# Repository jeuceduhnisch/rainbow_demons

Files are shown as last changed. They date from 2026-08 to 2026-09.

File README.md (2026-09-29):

# Rainbow Demons

Rainbow Demons is an independently designed Daisy Patch SM Eurorack
buffer-manipulation instrument.

## Releases

- The repository root preserves the original tested working build from
  2026-08-11, including its firmware, documentation and fabrication files.
- `Rainbow_Demons_v2/` contains the corrected 18HP hardware revision.
- `Rainbow_Demons_v2/release/` contains firmware and documentation v2.0.1.
- `Rainbow_Demons_v2/Rainbow_Demons_v2.0.1.zip` is the current complete release.
- `Rainbow_Demons_v2/Rainbow_Demons_v2.0.0.zip` remains the immutable rollback
  package.

## Version 2.0.1

Version 2 adds:

- Clock-toggle recording in Slice and Scatter: start, stop/play, start fresh.
- A Mode 2 Feedback density control that creates increasingly frequent and
  shorter randomized recording windows clockwise.
- Physical Record and REC CV priority over Mode 2 automation.
- Automatic four-second Slice and eight-second Scatter capture limits.
- A hardware-tested audio block-size correction that moves the callback cadence
  from an audible 3 kHz to 24 kHz and removes the high-pitched harmonic comb.

The v2.0.1 firmware was built, flashed, and tested on the target module on
2026-09-29. Tape, Slice, Scatter, recording, playback, three-head operation,
controls and mode switching passed without reported crackling or dropouts.

## Independent-design disclaimer

Rainbow Demons is inspired by broad buffer-manipulation ideas associated with
MTL ASM's Count to 5. It is not a clone, reproduction, port, or claim of exact
pedal behavior. No original source code, firmware, schematics, PCB files, or
proprietary design material were used. This project is not affiliated with or
endorsed by MTL ASM.

## License

This project is released under the Unlicense. See [LICENSE](LICENSE).

## Acknowledgments

Documentation, cleanup, and release organization were assisted by OpenAI Codex.

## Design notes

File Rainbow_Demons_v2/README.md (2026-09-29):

# Rainbow Demons v2

## Tape Delay 18HP All-In-One PCB and Faceplate

This revision corrects the Alpha RD901F potentiometer and QingPu WQP-PJ398SM / Thonkiconn footprints, fixes the rear-mounted Daisy Patch SM pin mirroring, and removes the carrier PCB material behind the top and bottom Eurorack rails. The separate faceplate remains the full 128.5 mm Eurorack height.

Electrical notes:

- 10-pin Eurorack power is routed as pins 1-2 `-12V`, pins 3-8 `GND`, pins 9-10 `+12V`.
- The Patch SM `3V3` output on A10 feeds the five potentiometer high-side pins.
- The Patch SM `5V` output is not used by this tape-delay control board.
- Potentiometers are wired as `GND / wiper signal / 3V3`.
- Pot electrical pads are on 2.50 mm centers and mounting tabs are 9.60 mm apart, matching KiCad's official Alpha RD901F-40-00D footprint.
- RV2 is rotated 180 degrees behind the panel so its real Alpha-style pin row clears the Daisy Patch SM A5/A6 area.
- FREEZE and REVERSE are momentary switches to ground using the Wurth `430476085716` 12 x 12 mm THT footprint.
- Each LED has two LED holes plus two inline series-resistor holes; install a resistor between `R_SIG` and `R_LED_A`.
- The square/rectangular LED hole is cathode/ground.
- The square/rectangular jack hole is sleeve/ground.
- Jack pad centers are sleeve `-6.48 mm`, switch normal `-3.38 mm`, and tip `+4.92 mm` relative to the panel jack center.
- Each jack includes the manufacturer-recommended 3.0 mm NPTH beneath the barrel center.
- The populated carrier outline is 91.44 x 111.50 mm, spanning panel coordinates y=8.50 through y=120.00; there is no carrier material in either rail zone.
- The rear-mounted Patch SM footprint is mirrored before rotation so carrier A1 lands on module A1, A5 on A5, and all other named pins remain one-to-one.
- IN R is normalled from IN L through the jack switch contact.
- IN R is normalled from IN L. The OUT L and OUT R switch contacts are intentionally unconnected.

Fabrication status:

- The main PCB and faceplate were generated as KiCad 10 PCB files.
- KiCad CLI DRC on 2026-07-21 reported 0 violations and 0 unconnected items for both generated boards.
- Run KiCad DRC again before ordering after any manual edits.
- This layout uses generic 9 mm vertical pot, QingPu/Thonkiconn PJ398SM-style 3-pin jack, and 5 mm LED footprints. Verify against the exact parts you will buy before a full production order.

Files:

- `tape_delay_all_in_one_18hp_v2.kicad_pcb`: routed main PCB with corrected footprints, power mapping, and rail clearance.
- `tape_delay_faceplate_18hp_v2.kicad_pcb`: matching full-height FR4 faceplate.
- `faceplate_editable.svg`: editable faceplate art/text template.
- `tape_delay_all_in_one_wiring_map.csv`: Patch SM pin assignments.
- `main_gerbers.zip`: main PCB fabrication package, after export.
- `faceplate_gerbers.zip`: faceplate fabrication package, after export.

## Firmware and build release 2.0.1

The complete clock-toggle and random-density firmware release is in
`release/`. It includes source, flashable binary, BOM, build guide, PCB
modifications, quick start and the six-page combined manual.

The packaged current release is `Rainbow_Demons_v2.0.1.zip`; the unchanged
`Rainbow_Demons_v2.0.0.zip` is retained for rollback. Version 2 adds clock-edge
start/stop recording in Slice and Scatter plus randomized Mode 2 recording
density on the Feedback control. Version 2.0.1 changes only the audio block
size from 16 to 2, moving the callback cadence from 3 kHz to 24 kHz. The new
firmware built, flashed and passed the complete hands-on mode test on
2026-09-29 without reported crackling or dropouts.

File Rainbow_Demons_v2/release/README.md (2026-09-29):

# Rainbow Demons v2.0.1

Version: 2.0.1
Release date: 2026-09-29

This package preserves the tested DIY Eurorack instrument, its established
recording behavior, the 2026-09-29 callback-noise correction and the tape-delay
PCB fabrication files actually used for the build.

## Independent-design disclaimer

Rainbow Demons is an independently designed instrument inspired by broad
buffer-manipulation ideas associated with MTL ASM's Count to 5. It is not a
clone, reproduction, port, or claim of exact pedal behavior. No original source
code, firmware, schematics, PCB files, or proprietary design material were
used. This project is not affiliated with or endorsed by MTL ASM.

## Start here

1. Read `PCB_MODIFICATIONS.md` before powering the tape-delay PCB.
2. Build from `BUILD_GUIDE.md` and `BOM.md`.
3. Flash `firmware/build/RainbowDemons.bin` or rebuild from source.
4. Use `QUICK_START.md` for the final control map.

The same material is combined into `Rainbow_Demons_Build_Documentation.pdf`.

## Package layout

- Top level - concise build guide, PCB changes, BOM, quick start and PDF.
- `firmware/` - final source, Makefile, startup file and verified binary.
- `pcb/` - tape-delay main PCB/faceplate Gerbers, source and base wiring map.

## Release firmware

- Binary size and SHA-256: see `firmware/BUILD_MANIFEST.txt` for the verified
  v2.0.1 build identity.
- Audio block size: 2 samples at 48 kHz; callback cadence 24 kHz
- Noise correction: removes the audible 3 kHz callback-rate harmonic comb
- Mode 3 head range: 1/8x to 8x, or -3 to +3 octaves
- Mix: counter-clockwise dry, clockwise wet, with hard digital endpoints
- REC CV alternates capture on successive clock edges: start / stop / start new
- Slice Feedback controls random-record density; clockwise produces more
  frequent, shorter windows; manual Record or the first
  REC CV edge takes priority until Reset or a mode change
- Changing Mode clears captured audio and invalidates the previous phrase

Hardware acceptance on 2026-09-29 passed Tape, Slice and Scatter, including
recording/playback, three heads, controls and mode switching, with no reported
crackling or dropouts.

## Gerber note

The included Gerbers are the tape-delay PCB files used for this build. They do
not contain the documented 100k pulldown, Reset-trigger bodge or new toggle
wiring as copper changes; apply those modifications manually.

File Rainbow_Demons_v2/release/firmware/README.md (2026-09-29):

# Final firmware

This source/binary pair is v2.0.1, the 2026-09-29 hardware-tested release. It
preserves the v2.0.0 behavior and changes the audio block size from 16 to 2 to
move the callback cadence from an audible 3 kHz to 24 kHz.

This is independent clean-room firmware for Rainbow Demons. See the top-level
README for the independent-design disclaimer.

## Flash the supplied binary

Enter DFU mode by holding BOOT, tapping RESET and releasing BOOT, then run from
Git Bash:

```sh
make program-dfu
```

## Rebuild and flash

```sh
make clean && make && make program-dfu
```

The Makefile falls back to the known-good SDK at
`C:/Users/Jeuce/Documents/Codex/2026-07-07/i-h/work`. On another system,
override `LIBDAISY_DIR` and `DAISYSP_DIR` on the command line.

See `BUILD_MANIFEST.txt` for the accepted binary hash and behavior summary.

## Callback-noise correction

The v2.0.0 build used a 16-sample block at 48 kHz. A phone recording showed a
stable comb at approximately 3, 6, 9 and 12 kHz, matching the 3 kHz callback
rate and its harmonics. The 2-sample diagnostic removed the audible squeal and
passed Tape, Slice and Scatter stress testing on the built module. No DSP,
control-map or hardware-pin behavior changed in v2.0.1.

## REC trigger behavior

In Slice and Scatter, successive rising edges on `GATE_IN_1/B10` alternate:

1. Start a fresh capture.
2. Stop capture and begin playback.
3. Start another fresh capture.

Slice still stops automatically at four seconds and Scatter at eight seconds.
The physical Record button retains hold-to-record behavior.

## Slice automatic recording

In Slice, Feedback is an internal random-record density control. Full
counter-clockwise disables it. Turning clockwise makes capture events more
frequent and their windows shorter: roughly 1.25-3.75 seconds near the sparse
end, 0.3-0.9 seconds near noon and 0.06-0.2 seconds fully clockwise.

A physical Record press or the first REC trigger edge latches manual/external
priority and disables the generator until Reset is pressed or the mode is
changed. The gate input cannot detect a cable held at 0 V, so external priority
begins on the first received rising edge, not at physical cable insertion.

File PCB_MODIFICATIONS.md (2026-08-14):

# Required modifications to the reused tape-delay PCB

These modifications convert the included tape-delay PCB wiring for Rainbow
Demons. See the top-level README for the independent-design disclaimer.

These changes match the final working firmware. Perform continuity checks with
the module unpowered.

## Required

1. **Audio-input pulldown:** add a 100k resistor from the audio input jack's
   switched/normal contact to GND. This prevents an open input from floating.
2. **Reset trigger:** the original CLOCK OUT tip runs to `B6/GATE_OUT_2`, which
   is an output. Isolate or ignore that trace and wire the jack tip to
   `B9/GATE_IN_2`. Keep the sleeve at GND.
3. **Record trigger:** retain the CLOCK IN connection to `B10/GATE_IN_1`.
4. **Buttons:** Record goes to `D1`; Reset goes to `D2`. Each button shorts its
   pin to GND when pressed.
5. **Mode toggle:** SPDT ON-OFF-ON, common to GND, outer lugs to `D7` and `D10`.
6. **Direction toggle:** common to GND, outer lugs to `D3` and `D4`.
7. **Quantize toggle:** common to GND, outer lugs to `D5` and `D6`.
8. **LEDs:** Record LED is driven from `B8`; Status LED from `B7`. Each LED
   requires a series resistor. The existing TEMPO/B8 position normally already
   has one; add 1k at B7 if the reused footprint has none.

## Final analog connections

| Panel control | Patch SM pin |
|---|---|
| Time pot | `A2 / ADC_9` |
| Feedback pot | `C8 / CV_7` |
| Mix pot | `C9 / CV_8` |
| Filter pot | `A3 / ADC_10` |
| Flutter pot | `D9 / ADC_11` |
| CV1 Time | `C5 / CV_1` |
| CV2 Filter | `C4 / CV_2` |
| CV3 Flutter | `C3 / CV_3` |
| CV4 Feedback | `C2 / CV_4` |
| CV5 | `C6 / CV_5`; unused by final firmware |
| Mono input | `B4 / AUDIO_IN_LEFT` |
| Main output | `B2 / AUDIO_OUT_LEFT` |
| Optional second output | `B1 / AUDIO_OUT_RIGHT` |

The final firmware reduced the recording-path overload that caused the
high-frequency tone. No additional input attenuator is required on the tested
module. Keep the 100k switched-contact pulldown.

## Leave disconnected

- Original `B6/GATE_OUT_2` connection to the repurposed Reset trigger jack.
- `B5/FREEZE LED`, unless deliberately repurposed in a future firmware build.
- Audio-input-right if building the tested mono version.
- CV5-to-Mix modulation; it is disabled so Mix can reach exact dry/wet endpoints.

## Unpowered checks

- No short between +12V, -12V, 5V, 3V3 and GND.
- Audio input normal contact measures about 100k to GND with no cable inserted.
- Trigger sleeves and toggle commons have continuity to GND.
- Reset trigger tip reaches B9 and does not reach B6.
- Eurorack red stripe reaches the PCB's marked -12V end.

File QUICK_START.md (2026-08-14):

# Quick start

These controls describe Rainbow Demons. See the top-level README for the
independent-design disclaimer.

## Global controls

| Control | Function |
|---|---|
| Mode toggle | Up Tape / center Slice / down Scatter |
| Direction toggle | Outer positions force forward or reverse; center is knob-controlled |
| Quantize toggle | Outer positions select semitone or octave; center is free |
| Mix | Counter-clockwise dry / clockwise wet |
| Record | Hold to capture in Slice or Scatter; release to play |
| Reset | Tap to restart heads; hold 1.2 seconds to erase |

Changing Mode clears all captured audio.

The final firmware reads the two outside toggle contacts directly. If an outer
position does not match the engraved panel word, exchange that toggle's two
outside wires; its center behavior does not change.

## Tape - pitch-shifted/reverse delay

| Knob | Function |
|---|---|
| Time | Read-head direction, speed and pitch |
| Feedback | Processed signal returned to the buffer |
| Mix | Dry/delay balance |
| Filter | Lo-fi bandwidth and brightness |
| Flutter | Stepped buffer length, about 31 ms to 8 s |

For unstable harmonized pitch spirals, raise Feedback and move Time away from unity.

## Slice - asynchronous random sampler

Hold Record for a phrase up to four seconds, then release.

| Knob | Function |
|---|---|
| Time | Slice direction, speed and pitch |
| Feedback | Reserved |
| Mix | Dry/sliced-sample balance |
| Filter | Random start probability/range |
| Flutter | Slice length, grains to full phrase |

## Scatter - one to three tape heads

Hold Record for a phrase up to eight seconds, then release.

| Knob | Function |
|---|---|
| Time | Head 1 direction/speed |
| Feedback | Head 2 direction/speed |
| Filter | Head 3 direction/speed |
| Flutter | One, two or three active heads |
| Mix | Dry/multi-head loop balance |

With Direction centered, each head runs reverse left of noon, stops near noon
and runs forward right of noon. Each spans 1/8x to 8x (-3 to +3 octaves), with
approximately 1x near 1:30.

## Reliable initial test settings

- Direction and Quantize centered.
- Time, Feedback and Filter at noon.
- Flutter at 2 o'clock.
- Leave CV inputs unpatched.
- Change only Mix while checking dry/wet behavior.

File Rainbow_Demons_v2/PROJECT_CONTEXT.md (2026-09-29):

# Rainbow Demons project context

Current release: v2.0.1, 2026-09-29.

The module is built from the Tape Delay V2 carrier PCB with the documented
100k input pulldown, B9 Reset-trigger bodge and Rainbow Demons control wiring.
The current firmware uses a 2-sample audio block at 48 kHz. This replaces the
v2.0.0 16-sample setting whose 3 kHz callback cadence produced an audible
harmonic comb on the built module.

The v2.0.1 binary was compiled, flashed and hardware-tested. Tape, Slice,
Scatter, recording/playback, all three Scatter heads, controls and mode
switching passed without reported crackling or dropouts.

Do not overwrite `Rainbow_Demons_v2.0.0.zip`; it is the rollback package.
Future experiments belong in new versioned folders or branches.

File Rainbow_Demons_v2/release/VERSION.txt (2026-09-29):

Module: Rainbow Demons
Release: v2.0.1
Date: 2026-09-29
Status: RELEASED - firmware built, flashed and hardware-tested
Source task: 019f78d2-ce77-7970-9f07-954e1e9a1d2a

Change summary:
- Audio block size changed from 16 to 2 samples at 48 kHz.
- Callback cadence moved from 3 kHz to 24 kHz.
- Audible callback-rate harmonic comb was no longer present in the hardware test.
- No DSP, control-map, pinout, PCB or panel change.

Verification:
- Clean firmware build passed.
- Binary size: 88252 bytes.
- SHA-256: C02E43BDFAF3293CE66D482667BFC05E70C1547ACF37449F2CC3C53EE25D94E8
- DFU flash passed.
- Tape, Slice, Scatter, recording/playback, three heads, controls and mode
  switching passed without reported crackling or dropouts.

Artifact status:
- Schematic/circuit explanation: Included in build documentation.
- BOM: Included.
- Physical PCB/layout files: Included as KiCad source and Gerbers.
- External wiring and PCB modifications: Included.
- Power and connector information: Included.
- Firmware source/build/upload instructions: Included.
- Bring-up and acceptance testing: Included.
- Editable sources and PDF: Included.

Rollback:
- Rainbow_Demons_v2.0.0.zip remains unchanged.

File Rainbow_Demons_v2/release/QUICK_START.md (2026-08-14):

# Quick start

These controls describe Rainbow Demons. See the top-level README for the
independent-design disclaimer.

## Global controls

| Control | Function |
|---|---|
| Mode toggle | Up Tape / center Slice / down Scatter |
| Direction toggle | Outer positions force forward or reverse; center is knob-controlled |
| Quantize toggle | Outer positions select semitone or octave; center is free |
| Mix | Counter-clockwise dry / clockwise wet |
| Record | Hold to capture in Slice or Scatter; release to play |
| REC CV | Rising pulses alternate: start / stop-and-play / start fresh |
| Reset | Tap to restart heads; hold 1.2 seconds to erase |

Changing Mode clears all captured audio.

For clocked recording, patch a standard positive Eurorack clock to REC CV
(0V low, +5V high recommended). Pulse width is not used; each rising edge
changes the capture state. If capture reaches four seconds in Slice or eight
seconds in Scatter, it stops automatically and the next pulse starts fresh.
RESET CV only restarts the playback heads; it does not begin a recording.

The final firmware reads the two outside toggle contacts directly. If an outer
position does not match the engraved panel word, exchange that toggle's two
outside wires; its center behavior does not change.

## Tape - pitch-shifted/reverse delay

| Knob | Function |
|---|---|
| Time | Read-head direction, speed and pitch |
| Feedback | Processed signal returned to the buffer |
| Mix | Dry/delay balance |
| Filter | Lo-fi bandwidth and brightness |
| Flutter | Stepped buffer length, about 31 ms to 8 s |

For unstable harmonized pitch spirals, raise Feedback and move Time away from unity.

## Slice - asynchronous random sampler

Hold Record for a phrase up to four seconds, then release.

| Knob | Function |
|---|---|
| Time | Slice direction, speed and pitch |
| Feedback | Auto-record density: clockwise makes captures more frequent and shorter |
| Mix | Dry/sliced-sample balance |
| Filter | Random start probability/range |
| Flutter | Slice length, grains to full phrase |

With Feedback above its CCW off zone, Slice automatically records random
windows. Sparse settings produce roughly 1.25-3.75-second captures; noon gives
about 0.3-0.9 seconds; fully clockwise gives about 0.06-0.2 seconds. Clockwise
also shortens the random wait between windows. Pressing Record or sending the
first REC CV pulse takes manual/external priority; automatic recording remains
disabled until Reset is pressed or you leave and return to Slice. Because the
digital input senses voltage rather than cable insertion, an inserted cable at
0 V is recognized only when its first rising edge arrives.

## Scatter - one to three tape heads

Hold Record for a phrase up to eight seconds, then release.

| Knob | Function |
|---|---|
| Time | Head 1 direction/speed |
| Feedback | Head 2 direction/speed |
| Filter | Head 3 direction/speed |
| Flutter | One, two or three active heads |
| Mix | Dry/multi-head loop balance |

With Direction centered, each head runs reverse left of noon, stops near noon
and runs forward right of noon. Each spans 1/8x to 8x (-3 to +3 octaves), with
approximately 1x near 1:30.

## Reliable initial test settings

- Direction and Quantize centered.
- Time and Filter at noon.
- Feedback at noon for Tape/Scatter; fully CCW for predictable manual Slice
  testing. Mode 2 no longer has a neutral noon Feedback setting.
- Flutter at 2 o'clock.
- Leave CV inputs unpatched.
- Change only Mix while checking dry/wet behavior.

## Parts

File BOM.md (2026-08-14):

# Final BOM

Quantities describe the tested mono Rainbow Demons build. The optional second output may
be added if the panel has room.

| Category | Qty | Part / value | Notes |
|---|---:|---|---|
| DSP | 1 | Electrosmith Daisy Patch SM | Main processor and Eurorack I/O conditioning |
| Main PCB | 1 | Tape-delay all-in-one Patch SM PCB | Main Gerbers included |
| Patch SM sockets | 4 | 1x10, 2.54 mm female headers | Keep the Patch SM removable |
| Power header | 1 | 2x5 keyed Eurorack header | Red stripe = -12V |
| Power cable | 1 | 10-to-16-pin Eurorack ribbon | Verify orientation at both ends |
| Pots | 5 | B10K linear | Time, Feedback, Mix, Filter, Flutter |
| Knobs | 5 | To fit pot shafts | About 10-12 mm diameter |
| Toggles | 3 | SPDT ON-OFF-ON | Mode, Direction, Quantize; common to GND |
| Buttons | 2 | SPST-NO momentary | Record and Reset |
| LEDs | 2 | 3 mm or 5 mm diffused | Record and Status |
| LED resistors | 2 | 1k, 0.25 W | One may already exist at TEMPO/B8 |
| Input pulldown | 1 | 100k, 0.25 W | Input switched contact to GND |
| Jacks | 9 | PJ398SM/PJ301M-12-style switched 3.5 mm | 5 CV, 2 trigger, mono in, mono out |
| Optional output jack | 1 | Same as above | Connect to B1 for mirrored output |
| Perfboard | 1 | 2.54 mm isolated pad-per-hole | Only if controls are not PCB-mounted |
| Hookup wire | 1 lot | 26-28 AWG stranded | Color-code power, ground, analog and digital |
| Bus wire | 1 lot | 22-24 AWG tinned solid | Ground/power buses if using perfboard |
| Heat-shrink | 1 kit | 1.5-4 mm | Insulate panel terminals and bodges |
| Standoffs/hardware | 1 set | M2.5/M3 nylon or insulated | Support carrier and perfboard independently |
| Front panel | 1 | Matching tape-delay PCB panel | Faceplate Gerbers included |

## Optional noise filtering

For long hand-wired pot leads, add one 1k resistor in series with each of the
five pot wipers and optionally 10 nF from the Patch SM side of each resistor to
GND. These are noise-control parts, not required for basic operation.

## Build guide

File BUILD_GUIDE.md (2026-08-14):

# Concise build guide

This guide builds Rainbow Demons using the tape-delay PCB and final firmware in
this package. See the top-level README for the independent-design disclaimer.

## 1. Mechanical dry fit

Dry-fit the panel, pots, toggles, buttons, LEDs, jacks, Patch SM carrier and any
perfboard before soldering. Confirm rail clearance, USB/BOOT access and that no
metal hardware can contact perfboard copper.

## 2. Power and carrier

Install the keyed 10-pin Eurorack header with the marked -12V edge at the red
stripe. Socket the Patch SM if possible. Do not feed external 5V or 3V3 into the
Patch SM output rails.

## 3. Pots and CV

Wire the five pots and CV jacks exactly as listed in `PCB_MODIFICATIONS.md`.
Pot end terminals go to the appropriate supply and GND; the wiper goes to the
listed ADC/CV pin. Ground every jack sleeve. CV inputs are already conditioned
by the Patch SM, so external attenuators are optional.

## 4. Audio and triggers

- Mono input tip -> B4; sleeve -> GND.
- Add 100k from the input jack switched/normal contact to GND.
- Main output tip -> B2; optional mirrored output -> B1.
- Record trigger tip -> B10.
- Isolate the reused Reset jack from B6 and wire its tip -> B9.

## 5. Digital controls

- Record button -> D1 to GND.
- Reset button -> D2 to GND.
- Mode toggle outer lugs -> D7/D10; common -> GND.
- Direction toggle outer lugs -> D3/D4; common -> GND.
- Quantize toggle outer lugs -> D5/D6; common -> GND.
- Record LED -> B8 through 1k; Status LED -> B7 through 1k; cathodes -> GND.

If a toggle reads upside-down, exchange only its two outside wires.

## 6. Unpowered inspection

Check the rail isolation, red-stripe orientation, B9 Reset bodge, 100k input
pulldown, LED polarity/resistors, jack grounds and adjacent-header shorts.

## 7. Flash firmware

Put the Patch SM in DFU mode: hold BOOT, tap RESET, then release BOOT. From Git
Bash in the included `firmware` directory run:

```sh
make program-dfu
```

To rebuild first:

```sh
make clean && make && make program-dfu
```

The supplied Makefile uses the complete SDK at
`C:/Users/Jeuce/Documents/Codex/2026-07-07/i-h/work` when the nearby
DaisyExamples SDK is incomplete. Override `LIBDAISY_DIR` and `DAISYSP_DIR` on
the make command line on another computer.

## 8. First power and acceptance test

1. Power from a current-limited/test Eurorack supply if available.
2. Confirm no component heats and the Patch SM starts normally.
3. With Mix fully counter-clockwise, confirm clean dry audio.
4. With Mix fully clockwise, confirm no direct-signal leakage.
5. Record and play a phrase in Slice.
6. Record in Scatter; verify three heads with Flutter high.
7. In Scatter, verify Time, Feedback and Filter run reverse-left, stop near
   noon and run forward-right with Direction centered.
8. Change modes and return; the old capture must not resume.

Do not install the module in the main case until these checks pass.

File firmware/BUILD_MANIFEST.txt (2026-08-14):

Rainbow Demons - final working firmware
Release: 2026-08-11
Target: Daisy Patch SM / STM32H750
Source: RainbowDemons.cpp
Binary: build/RainbowDemons.bin
Binary size: 87208 bytes
SHA-256: 661A7DB0510F7DD0625B3B4981CDC01A40592A78591653F14ADCE66548FBF970
Build command: make clean && make
Flash command: make program-dfu

Independent-design notice: see the top-level README.

Acceptance status reported by builder:
- Mix reaches true dry; working wet endpoint confirmed.
- 100k input pulldown fixed open-input behavior.
- Mode 3 head 2 direction and center calibrated.
- Mode 3 range set to -3 through +3 octaves.
- Mode changes invalidate and clear the previous capture.

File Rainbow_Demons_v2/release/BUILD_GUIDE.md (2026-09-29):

# Concise build guide

This guide builds Rainbow Demons using the tape-delay PCB and final firmware in
this package. See the top-level README for the independent-design disclaimer.

## 1. Mechanical dry fit

Dry-fit the panel, pots, toggles, buttons, LEDs, jacks, Patch SM carrier and any
perfboard before soldering. Confirm rail clearance, USB/BOOT access and that no
metal hardware can contact perfboard copper.

## 2. Power and carrier

Install the keyed 10-pin Eurorack header with the marked -12V edge at the red
stripe. Socket the Patch SM if possible. Do not feed external 5V or 3V3 into the
Patch SM output rails.

## 3. Pots and CV

Wire the five pots and CV jacks exactly as listed in `PCB_MODIFICATIONS.md`.
Pot end terminals go to the appropriate supply and GND; the wiper goes to the
listed ADC/CV pin. Ground every jack sleeve. CV inputs are already conditioned
by the Patch SM, so external attenuators are optional.

## 4. Audio and triggers

- Mono input tip -> B4; sleeve -> GND.
- Add 100k from the input jack switched/normal contact to GND.
- Main output tip -> B2; optional mirrored output -> B1.
- Record trigger tip -> B10. Successive rising clock edges perform
  start-recording / stop-and-play / start-new-recording.
- Isolate the reused Reset jack from B6 and wire its tip -> B9.

## 5. Digital controls

- Record button -> D1 to GND.
- Reset button -> D2 to GND.
- Mode toggle outer lugs -> D7/D10; common -> GND.
- Direction toggle outer lugs -> D3/D4; common -> GND.
- Quantize toggle outer lugs -> D5/D6; common -> GND.
- Record LED -> B8 through 1k; Status LED -> B7 through 1k; cathodes -> GND.

If a toggle reads upside-down, exchange only its two outside wires.

## 6. Unpowered inspection

Check the rail isolation, red-stripe orientation, B9 Reset bodge, 100k input
pulldown, LED polarity/resistors, jack grounds and adjacent-header shorts.

## 7. Flash firmware

Put the Patch SM in DFU mode: hold BOOT, tap RESET, then release BOOT. From Git
Bash in the included `firmware` directory run:

```sh
make program-dfu
```

To rebuild first:

```sh
make clean && make && make program-dfu
```

The supplied Makefile uses the complete SDK at
`C:/Users/Jeuce/Documents/Codex/2026-07-07/i-h/work` when the nearby
DaisyExamples SDK is incomplete. Override `LIBDAISY_DIR` and `DAISYSP_DIR` on
the make command line on another computer.

## 8. First power and acceptance test

1. Power from a current-limited/test Eurorack supply if available.
2. Confirm no component heats and the Patch SM starts normally.
3. With Mix fully counter-clockwise, confirm clean dry audio.
4. With Mix fully clockwise, confirm no direct-signal leakage.
5. Record and play a phrase in Slice.
6. Record in Scatter; verify three heads with Flutter high.
7. In Slice or Scatter, send three REC trigger pulses: pulse 1 starts capture,
   pulse 2 stops for playback, and pulse 3 starts a fresh capture.
8. In Scatter, verify Time, Feedback and Filter run reverse-left, stop near
   noon and run forward-right with Direction centered.
9. Change modes and return; the old capture must not resume.
10. In Slice, turn Feedback fully CCW and confirm automatic recording is off.
    Turn it clockwise and confirm randomized capture windows become more
    frequent and shorter. Press Record or send a REC pulse and confirm
    automation yields until Reset or a mode change.
11. With the input grounded and USB disconnected, listen at dry, noon and wet
    Mix positions. The previous 3 kHz callback squeal should not be audible.
12. Stress Tape at high feedback, Slice at maximum density, and Scatter with
    all three heads. Stop if crackling or audio dropouts occur.

Do not install the module in the main case until these checks pass.

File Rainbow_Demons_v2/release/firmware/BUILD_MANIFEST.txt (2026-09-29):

Rainbow Demons - final working firmware
Version: 2.0.1
Release: 2026-09-29
Target: Daisy Patch SM / STM32H750
Source: RainbowDemons.cpp
Binary: build/RainbowDemons.bin
Binary size: 88252 bytes
SHA-256: C02E43BDFAF3293CE66D482667BFC05E70C1547ACF37449F2CC3C53EE25D94E8
Build command: make clean && make
Flash command: make program-dfu

Independent-design notice: see the top-level README.

Working-baseline acceptance status reported by builder:
- Mix reaches true dry; working wet endpoint confirmed.
- 100k input pulldown fixed open-input behavior.
- Mode 3 head 2 direction and center calibrated.
- Mode 3 range set to -3 through +3 octaves.

2026-08-13 additions (build verified; hardware test pending):
- REC trigger pulses alternate start / stop / start-new capture.
- Slice Feedback controls automatic-record density (more frequent and shorter
  clockwise); Record or the
  first REC pulse latches manual/external priority until Reset or mode change.
- Mode changes invalidate and clear the previous capture.

2026-09-29 callback-noise correction (build, flash and hardware test passed):
- Audio block size changed from 16 to 2 samples at 48 kHz.
- Callback cadence moved from 3 kHz to 24 kHz.
- The audible 3/6/9/12 kHz harmonic comb was no longer present in the hardware test.
- Tape, Slice, Scatter, recording/playback, three heads, controls and mode
  switching passed without reported crackling or dropouts.

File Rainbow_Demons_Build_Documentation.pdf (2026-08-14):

Rainbow Demons - independent Patch SM instrument - 2026-08-11 | Page 1

# Rainbow Demons

## An original, independently designed Eurorack instrument

Release | Platform | Format | Firmware status
2026-08-11 | Daisy Patch SM | Tape-delay PCB / mono | Built and user-verified

# What this package contains

- Final source, Makefile, startup file and verified flashable binary.
- Tape-delay main PCB and faceplate Gerbers plus editable PCB source.
- Required PCB modifications, BOM, build sequence, acceptance test and quick-start control map.

# Critical proven modifications

Add 100k from the audio-input switched contact to GND. Move the repurposed Reset-trigger tip from B6 to B9/GATE_IN_2. Record is D1, Reset is D2, Record LED is B8 and Status LED is B7. Feedback uses CV_7/C8. Do not restore obsolete ADC_12, D7/D10-button or B5/B6-LED assignments.

## Verified behavior

- Mix is counter-clockwise dry and clockwise wet with exact digital endpoints.
- Tape provides lo-fi pitch/reverse delay and high-feedback pitch spirals.
- Slice captures up to 4 seconds; Scatter captures up to 8 seconds.
- Scatter heads span 1/8x to 8x (-3 to +3 octaves) and stop near noon.
- Changing Mode clears and invalidates the previous capture.

## Independent-design disclaimer

Rainbow Demons is inspired by broad buffer-manipulation ideas associated with MTL ASM's Count to 5. It is not a clone, reproduction, port, or claim of exact pedal behavior. No original source code, firmware, schematics, PCB files, or proprietary design material were used. This project is not affiliated with or endorsed by MTL ASM.

Rainbow Demons - independent Patch SM instrument - 2026-08-11 | Page 2

# 1. Required tape-delay PCB changes

Change | Final connection | Reason
Input pulldown | 100k: input switched/normal contact to GND | Stops floating open input
Reset trigger | Isolate original B6 trace; jack tip to B9 | B6 is an output; B9 is GATE_IN_2
Record trigger | Jack tip to B10 | GATE_IN_1
Buttons | Record D1; Reset D2; other side GND | Matches final panel/firmware
Mode toggle | Outer lugs D7/D10; common GND | Tape / Slice / Scatter
Direction | Outer lugs D3/D4; common GND | Reverse / variable / forward
Quantize | Outer lugs D5/D6; common GND | Semitone / free / octave
LEDs | B8 Record; B7 Status; each through 1k | Plain GPIO indicators

## Final signal map

Function | Pin | Function | Pin
Time pot | A2 / ADC_9 | CV1 Time | C5 / CV_1
Feedback pot | C8 / CV_7 | CV2 Filter | C4 / CV_2
Mix pot | C9 / CV_8 | CV3 Flutter | C3 / CV_3
Filter pot | A3 / ADC_10 | CV4 Feedback | C2 / CV_4
Flutter pot | D9 / ADC_11 | CV5 | C6 / disabled
Mono input | B4 | Main output | B2
Optional output | B1 | Ground | Jack sleeves / commons

## Leave disconnected

- B6 from the repurposed Reset trigger jack; B5 FREEZE LED; audio-input-right in the mono build.
- CV5-to-Mix modulation. The final firmware disables it to preserve exact Mix endpoints.

## Unpowered checks

- No shorts among +12V, -12V, 5V, 3V3 and GND; red stripe reaches marked -12V.
- Input normal contact measures about 100k to GND; Reset tip reaches B9 and not B6.
- Toggle commons and jack sleeves reach GND; LEDs have correct polarity and series resistors.

Rainbow Demons - independent Patch SM instrument - 2026-08-11 | Page 3

# 2. Bill of materials

Qty | Part | Specification / note
1 | Daisy Patch SM | DSP and conditioned Eurorack I/O
1 | Tape-delay main PCB | Main Gerbers included
4 | Patch SM sockets | 1x10, 2.54 mm female headers
1 | Power header + cable | 2x5 keyed; 10-to-16-pin ribbon; red stripe -12V
5 | Potentiometers + knobs | B10K linear; Time, Feedback, Mix, Filter, Flutter
3 | Toggles | SPDT ON-OFF-ON, panel mount
2 | Buttons | SPST-NO momentary, Record and Reset
2 | LEDs + 1k resistors | Diffused 3 or 5 mm; Record and Status
1 | 100k resistor | 0.25 W input switched-contact pulldown
9 | Switched 3.5 mm jacks | 5 CV, 2 trigger, mono input, mono output
1 opt. | Second output jack | Tip to B1 for mirrored output
1 | Perfboard | 2.54 mm isolated pad-per-hole if controls are hand-wired
1 lot | Wire / heat-shrink | 26-28 AWG stranded; 22-24 AWG tinned bus wire
1 set | Insulated hardware | M2.5/M3 standoffs, washers, rack screws
1 | Front panel | Matching faceplate Gerbers included

## Optional hand-wiring filter

For long pot leads, add 1k in series with each of five wipers and optionally 10 nF from the Patch SM side of each resistor to GND. These parts reduce pickup; they are not required for basic operation.

## Mechanical rules

- Dry-fit every control, carrier and perfboard before soldering; preserve rail and USB/BOOT clearance.
- Support carrier and perfboard with insulated hardware. Never let perfboard copper rest on the carrier.
- Verify exact pot shaft/bushing, toggle action and jack footprint against purchased parts.

Rainbow Demons - independent Patch SM instrument - 2026-08-11 | Page 4

# 3. Assembly, flashing and checkout

Step | Task | Action
1 | Mechanical dry fit | Fit panel controls, carrier and brackets. Confirm rail and USB/BOOT access.
2 | Power | Install keyed header with red stripe at -12V. Do not feed external 5V/3V3 into Patch SM outputs.
3 | Analog wiring | Wire pots/CVs per page 2. Ground sleeves. Add the 100k input pulldown.
4 | Audio/triggers | Input B4; output B2; Record trigger B10; isolate B6 and bodge Reset trigger to B9.
5 | Digital wiring | Record D1, Reset D2, toggles D3/D4/D5/D6/D7/D10, LEDs B8/B7.
6 | Inspect | Meter rails, grounds, pulldown, B9 bodge, LED polarity and adjacent-header shorts.

## Flash

Enter DFU: hold BOOT, tap RESET, release BOOT. In Git Bash inside the firmware folder:

Use | Command
Flash supplied build | make program-dfu
Clean rebuild + flash | make clean && make && make program-dfu

## Acceptance test

- Power from a test/current-limited supply; stop if anything heats or current is abnormal.
- Mix fully counter-clockwise: clean dry audio. Fully clockwise: wet only, no direct leakage.
- Slice: hold Record, capture a phrase, release and hear playback.
- Scatter: capture, raise Flutter for three heads; Time/Feedback/Filter reverse left, stop near noon, forward right.
- Change Mode and return. The old phrase must not resume.

## Binary identity

RainbowDemons.bin - final binary identity is listed in BUILD_MANIFEST.txt.
661A7DB0510F7DD0625B3B4981CDC01A40592A78591653F14ADCE66548FBF970

Rainbow Demons - independent Patch SM instrument - 2026-08-11 | Page 5

# 4. Quick start

Global control | Action
Mode | Up Tape / center Slice / down Scatter
Direction | Outer positions force direction; center lets DIR knobs cross reverse-stop-forward
Quantize | Outer positions select semitone/octave; center is free
Mix | Counter-clockwise dry / clockwise wet
Record | Hold to capture in Slice/Scatter; release to play
Reset | Tap restarts heads; hold 1.2 seconds erases
If an outer toggle label is reversed, exchange only that toggle's two outside wires.

## Mode control map

Knob | Tape | Slice | Scatter
Time | Read-head speed/direction | Slice speed/direction | Head 1 speed/direction
Feedback | Feedback amount | Reserved | Head 2 speed/direction
Mix | Dry/delay | Dry/slices | Dry/multi-head loop
Filter | Lo-fi tone/bandwidth | Random start probability | Head 3 speed/direction
Flutter | Stepped 31 ms-8 s length | Grain/full-phrase length | 1, 2 or 3 heads

## Mode notes

- Tape: high Feedback plus Time away from unity creates cascading, unstable harmonized pitch spirals.
- Slice: capture is up to 4 seconds; Filter raises random slice jumps; Flutter changes slice length.
- Scatter: capture is up to 8 seconds; each head spans 1/8x-8x (-3 to +3 octaves), about 1x near 1:30.
- Changing Mode always clears captured audio.

## Repeatable test setup

- Direction and Quantize centered; Time, Feedback and Filter at noon; Flutter at 2 o'clock.
- Leave CV inputs unpatched and change only Mix while verifying dry/wet behavior.

Rainbow Demons - independent Patch SM instrument - 2026-08-11 | Page 6

# 5. Release files and fabrication notes

Folder | Contents | Use
Top level | Build guide, modifications, BOM, quick start, PDF | Workshop reference
firmware/ | Source, Makefile, startup, binary, manifest | Rebuild or flash final firmware
pcb/ | Main/faceplate Gerbers, source, base map | Fabrication files; apply page 2 bodges

## Gerber warning

The included tape-delay PCB Gerbers reproduce the supplied V2 carrier layout. They do not include the 100k input pulldown, B9 Reset-trigger bodge or final Rainbow Demons toggle wiring as copper revisions. Apply those changes manually, or update the KiCad source and rerun DRC before ordering a native revision.

## Firmware build environment

- Target Daisy Patch SM / STM32H750; internal flash address 0x08000000.
- The included Makefile checks libDaisy, CMSIS and DaisySP before compiling.
- On another computer, override LIBDAISY_DIR and DAISYSP_DIR rather than hard-editing source paths.

## Final preservation checklist

- Keep the release ZIP unchanged as the known-working baseline.
- Make experimental firmware in a new folder; do not overwrite this binary/source pair.
- Photograph the B9 bodge, 100k pulldown, red-stripe orientation and Patch SM orientation for the build record.
- If controls are replaced, confirm pot polarity and exchange toggle outer wires as needed.

## Completed and user-verified 2026-08-11

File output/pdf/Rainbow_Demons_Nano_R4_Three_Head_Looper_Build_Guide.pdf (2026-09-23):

# RAINBOW DEMONS / DIRECT-MOUNT PROTOBOARD

# A buildable two-board reference

Every panel control is mechanically mounted to the top protoboard. No control or jack floats on a faceplate and there is only one board-to-board connector.

# Locked architecture

Use two matching 24-column x 44-row isolated-pad boards at 2.54mm pitch. The Top Control Board holds all five pots, both toggles, both buttons, the bicolor LED and four jacks. The Main Board holds Nano R4, SRAM, TL074, power protection, audio and CV circuits.

J1 is a single 1x20 stack connector at C44-V44. Four M3 standoffs at D14, T14, D43 and T43 carry mechanical load. J2 and J3 do not exist in this revision.

# Historically matched hardware

Hardware | Required family
Pots | Alpha RD901F-40-00D, 9mm vertical, B10K
Jacks | QingPu WQP-PJ398SM / Thonkiconn style
Buttons | Wurth 430476085716, 12x12mm THT
Quantize | Tayda A-5290, SPDT ON-OFF-ON
Loop/Shot | A-5291-style SPDT ON-ON, same 2.54mm pin pitch
LED | 5mm, 3-lead common-cathode red/green

# Important protoboard rule

These controls use their real historical footprints. Some holes fall between the stock 2.54mm pads. Drill those lead and locating holes using page 4, then bridge each hardware lead to the named isolated pad on page 5 with the shortest possible tinned solid link. The hardware body remains directly attached to the Top Board.

Rev 2.0 | 23 Sep 2026 | two 24 x 44 isolated-pad boards | physical build untested | 1 / 17

# BOM tied to the coordinate layouts

Reference designators and values match the placement and connection pages.

Qty Value Type | Qty | Hardware Use

## 4 100K resistor / PTC

## 1 100mA PTC resistor / PTC

10 100n ceramic or film | 4 | WQP-PJ398SM audio/CV jacks

## 8 10K resistor / PTC

## 4 10u electrolytic

9 1K resistor / PTC | 1 | Tayda A-5290 Quantize

## 3 1M resistor / PTC

## 2 1N4148 diode

2 1N5817 diode | 1 | 5mm bicolor common-cathode LED status

## 1 1u film ceramic or film

## 1 22n ceramic or film

1 250mA PTC resistor / PTC | 1 | 23LC1024-I/P + DIP-8 socket U2

## 2 2N3904 transistor

## 1 39K resistor / PTC

1 4.7u electrolytic | 1 | 1x20 stack header pair J1

## 2 BAT85 diode

## 1 VIN ENABLE jumper

5 | Alpha RD901F B10K P1-P5
2 | Wurth 430476085716 Record / Play
1 | A-5291 style ON-ON Loop / Shot
1 | Arduino Nano R4 socketed
1 | TL074CP + DIP-14 socket U1
1 | 2x5 Eurorack power header J_PWR
2 | 24x44 isolated-pad boards | minimum hole span 58.42 x 109.22mm
4 | M3 10-12mm standoffs | board stack
Rev 2.0 | 23 Sep 2026 | two 24 x 44 isolated-pad boards | physical build untested | 2 / 17

# The only inter-board connector

J1 is one straight 1x20 header. Pin 1 is C44 on both boards and pin 20 is V44.

Pin | Hole | Net
1 | C44 | +5N
2 | D44 | GND
3 | E44 | HEAD1
4 | F44 | HEAD2
5 | G44 | HEAD3
6 | H44 | AGE
7 | I44 | MIX
8 | J44 | REC_BTN
9 | K44 | PLAY_BTN
10 | L44 | Q_OCT
11 | M44 | Q_SEMI
12 | N44 | PLAY_MODE
13 | O44 | LED_R_OUT
14 | P44 | LED_G_OUT
15 | Q44 | AUDIO_IN_TIP
16 | R44 | AUDIO_OUT_TIP
17 | S44 | REC_TIP
18 | T44 | PLAY_TIP
19 | U44 | GND
20 | V44 | GND

# Stacking

# Fit a 1x20 female socket to the Main Board and the matching long-pin male header to the Top Board. Mark pin 1 at C44 in red on both boards

before soldering.

# Fit M3 standoffs at D14, T14, D43 and T43. The header carries signals only; the standoffs resist

control and patch-cable forces.

# No panel harness

# Pots, switches, buttons, LED and jacks terminate on the Top Board. Their shared +5V and ground buses also live there. Nothing

connects through loose J2/J3 wiring.

# J_PWR remains on the Main Board so rack power never travels through the control

hardware board.

Rev 2.0 | 23 Sep 2026 | two 24 x 44 isolated-pad boards | physical build untested | 3 / 17

# Top Control Board - real hardware footprints

Component side. Gold outlines show the actual historical hardware bodies and lead patterns; blue squares are J1.

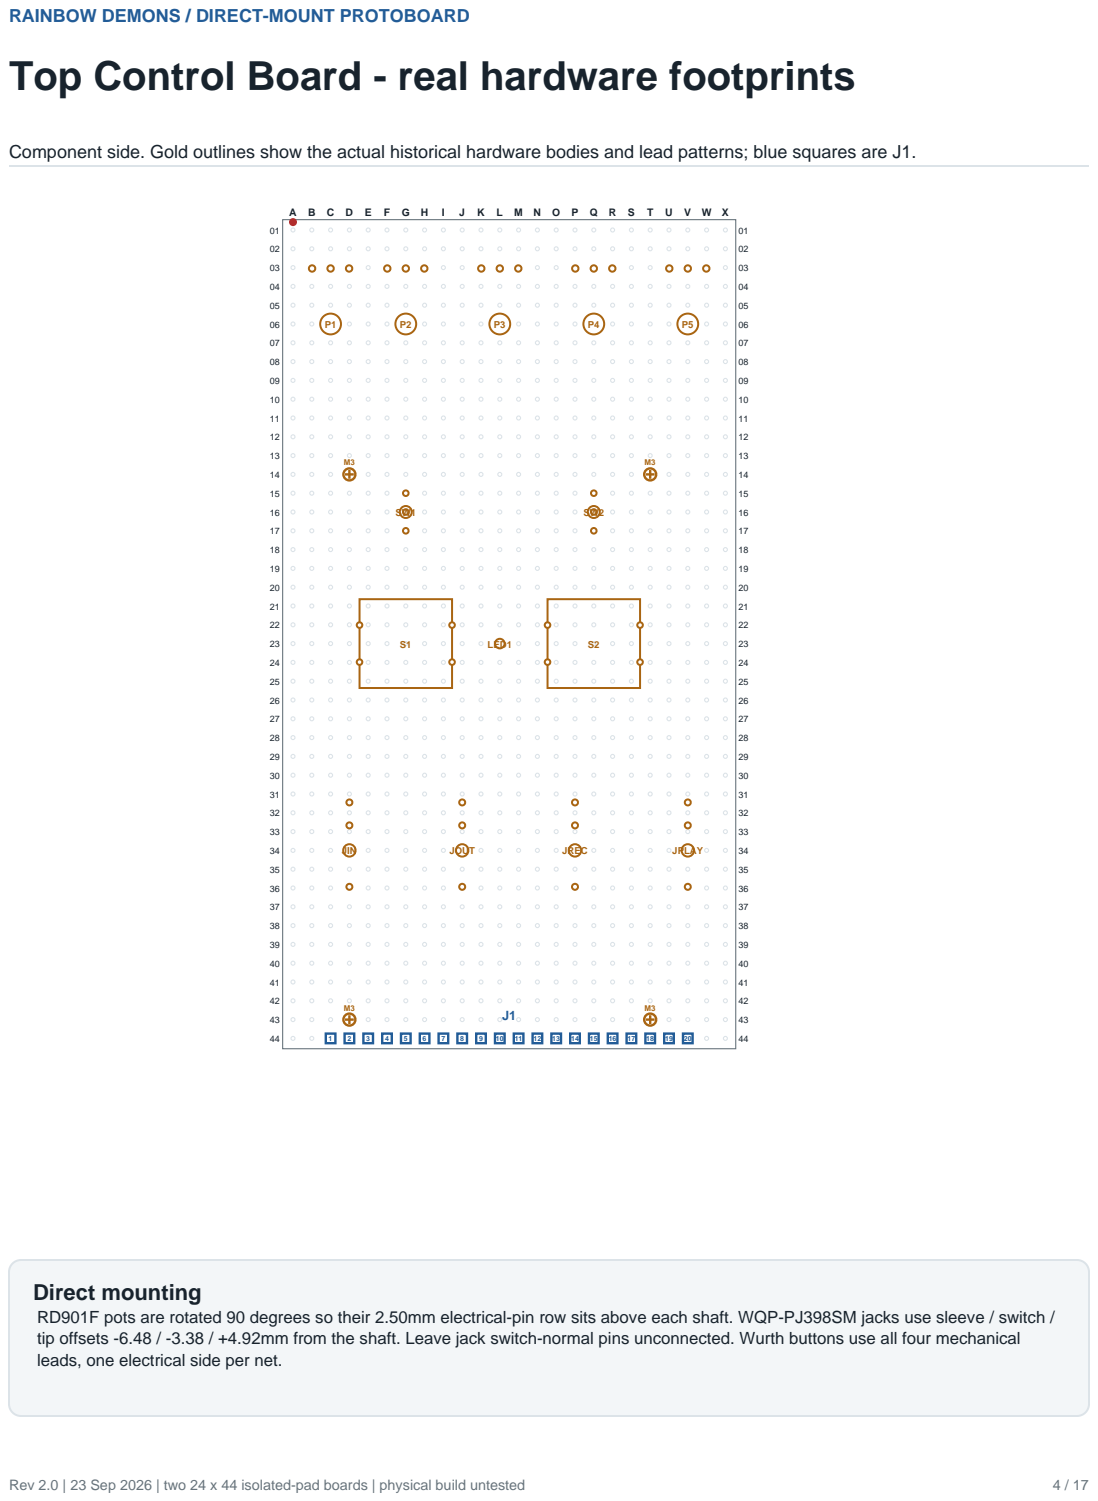
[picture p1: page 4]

Direct mounting
RD901F pots are rotated 90 degrees so their 2.50mm electrical-pin row sits above each shaft. WQP-PJ398SM jacks use sleeve / switch /
tip offsets -6.48 / -3.38 / +4.92mm from the shaft. Leave jack switch-normal pins unconnected. Wurth buttons use all four mechanical
leads, one electrical side per net.

# Top Control Board - lead-to-pad bridges

After drilling the exact footprints, bridge each listed hardware lead to the named isolated pad with a short rigid tinned lead.

Ref | Historical part | Named grid-pad bridge
P1 | HEAD 1 / RD901F | B3=+5N; C3=HEAD1; D3=GND
P2 | HEAD 2 / RD901F | F3=+5N; G3=HEAD2; H3=GND
P3 | HEAD 3 / RD901F | K3=+5N; L3=HEAD3; M3=GND
P4 | AGE / RD901F | P3=+5N; Q3=AGE; R3=GND
P5 | MIX / RD901F | U3=+5N; V3=MIX; W3=GND
SW1 | A-5290 QUANTIZE | G15=Q_OCT; G16=GND; G17=Q_SEMI
SW2 | A-5291 LOOP/SHOT | Q15=PLAY_MODE; Q16=GND
S1 | WURTH RECORD | E22=REC_BTN; J24=GND
S2 | WURTH PLAY | O22=PLAY_BTN; T24=GND
LED1 | 5MM RED/GREEN | K23=LED_R_OUT; L23=GND; M23=LED_G_OUT
JIN | PJ398SM AUDIO IN | D31=GND; D36=AUDIO_IN_TIP
JOUT | PJ398SM AUDIO OUT | J31=GND; J36=AUDIO_OUT_TIP
JREC | PJ398SM RECORD CV | P31=GND; P36=REC_TIP
JPLAY | PJ398SM PLAY CV | V31=GND; V36=PLAY_TIP

# Orientation rules

Pot pins are +5V / wiper / GND in the order printed above; reverse the two outer connections only if the physical rotation is opposite. SW1 centre is GND and its two throws are octave/semitone. SW2 common is GND and its selected throw is PLAY_MODE. LED centre lead is common cathode GND.

Rev 2.0 | 23 Sep 2026 | two 24 x 44 isolated-pad boards | physical build untested | 5 / 17

# Top solder pass 1 - shared +5V and ground

Solder side, mirrored. The A-column +5V and X-column ground spines eliminate repeated harness returns.

X W V U T S R Q P O N M L K J I H G F E D C B A
01 | 01
02 | 02
03 | 03
04 | 04
05 | 05
06 | 06
07 | 07
08 | 08
09 | 09
10 | 10
11 | 11
12 | 12
13 | 13
14 | 14
15 | 15
16 | 16
17 | 17
18 | 18
19 | 19
20 | 20
21 | 21
22 | 22
23 | 23
24 | 24
25 | 25
26 | 26
27 | 27
28 | 28
29 | 29
30 | 30
31 | 31
32 | 32
33 | 33
34 | 34
35 | 35
36 | 36
37 | 37
38 | 38
39 | 39
40 | 40
41 | 41
42 | 42
43 | 43
44 | 44
ID | Endpoints | Net
T001 | A6..A43 ALL | +5N
T002 | B3-A6 | +5N
T003 | F3-A6 | +5N
T004 | K3-A6 | +5N
T005 | P3-A6 | +5N
T006 | U3-A6 | +5N
T007 | C44-A43 | +5N
T011 | X6..X43 ALL | GND
T012 | D3-X6 | GND
T013 | H3-X6 | GND
T014 | M3-X6 | GND
T015 | R3-X6 | GND
T016 | W3-X6 | GND
ID | Endpoints | Net
T017 | G16-X16 | GND
T018 | Q16-X16 | GND
T019 | J24-X24 | GND
T020 | T24-X24 | GND
T021 | L23-X23 | GND
T022 | D31-X31 | GND
T023 | J31-X31 | GND
T024 | P31-X31 | GND
T025 | V31-X31 | GND
T026 | D44-X43 | GND
T027 | U44-X43 | GND
T028 | V44-X43 | GND

# Meter before J1

All pot high sides reach +5N. All pot low sides, jack sleeves, button returns, toggle commons and LED cathode reach GND. +5N and GND must remain open to each other.

Rev 2.0 | 23 Sep 2026 | two 24 x 44 isolated-pad boards | physical build untested | 6 / 17

# Top wiring - controls and jack tips

Solder side, mirrored. Each green route terminates at exactly one J1 signal pin.

X W V U T S R Q P O N M L K J I H G F E D C B A
01 | 01
02 | 02
03 | 03
04 | 04
05 | 05
06 | 06
07 | 07
08 | 08
09 | 09
10 | 10
11 | 11
12 | 12
13 | 13
14 | 14
15 | 15
16 | 16
17 | 17
18 | 18
19 | 19
20 | 20
21 | 21
22 | 22
23 | 23
24 | 24
25 | 25
26 | 26
27 | 27
28 | 28
29 | 29
30 | 30
31 | 31
32 | 32
33 | 33
34 | 34
35 | 35
36 | 36
37 | 37
38 | 38
39 | 39
40 | 40
41 | 41
42 | 42
43 | 43
44 | 44
ID | Endpoints | Net
T008 | Q3-H44 | AGE
T009 | D36-Q44 | AUDIO_IN_TIP
T010 | J36-R44 | AUDIO_OUT_TIP
T029 | C3-E44 | HEAD1
T030 | G3-F44 | HEAD2
T031 | L3-G44 | HEAD3
T032 | M23-P44 | LED_G_OUT
T033 | K23-O44 | LED_R_OUT
ID | Endpoints | Net
T034 | V3-I44 | MIX
T035 | O22-K44 | PLAY_BTN
T036 | Q15-N44 | PLAY_MODE
T037 | V36-T44 | PLAY_TIP
T038 | G15-L44 | Q_OCT
T039 | G17-M44 | Q_SEMI
T040 | E22-J44 | REC_BTN
T041 | P36-S44 | REC_TIP

# No floating controls

## Every control body is soldered or mechanically fixed to this board. The only short links are the rigid lead-to-pad bridges

documented on page 5; there is no faceplate harness.

Rev 2.0 | 23 Sep 2026 | two 24 x 44 isolated-pad boards | physical build untested | 7 / 17

# Main Board - complete component placement

Component side. All active electronics and Eurorack power remain on this lower board.

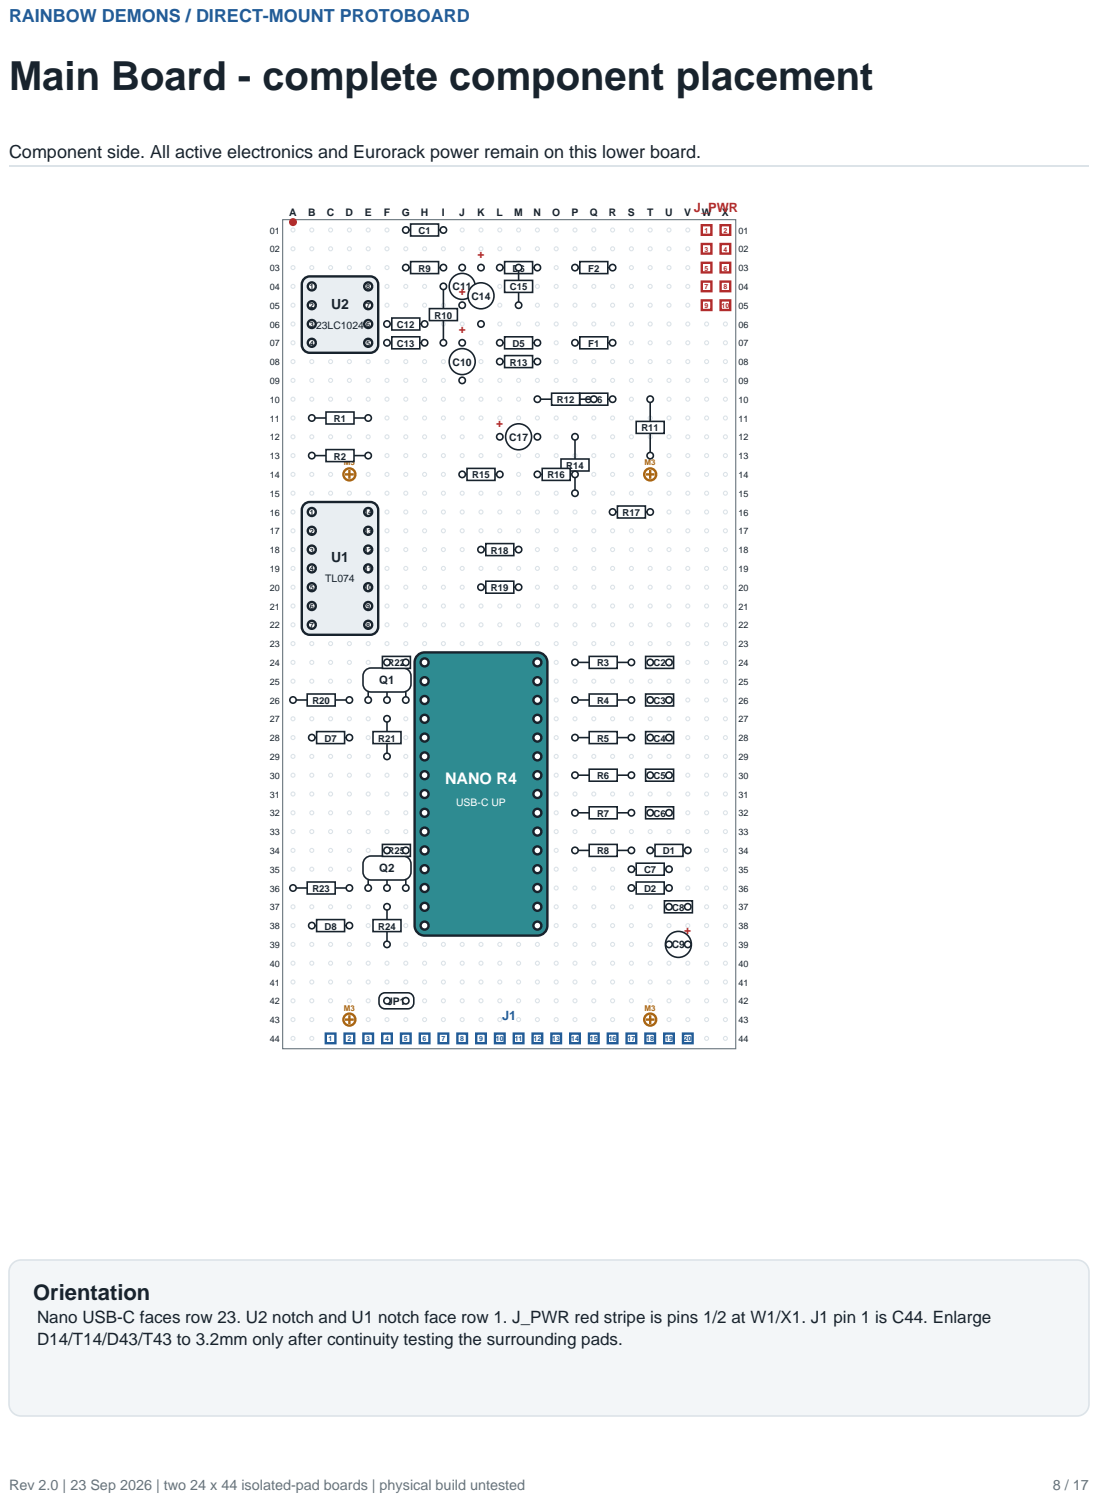
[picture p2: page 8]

Orientation
Nano USB-C faces row 23. U2 notch and U1 notch face row 1. J_PWR red stripe is pins 1/2 at W1/X1. J1 pin 1 is C44. Enlarge
D14/T14/D43/T43 to 3.2mm only after continuity testing the surrounding pads.

# Main Board - exact coordinates, part 1

These lead holes are authoritative when labels crowd the placement drawing.

Ref | Value | Lead holes | Nets
R1 | 10K | B11 / E11 | SIO2 / +5N
R2 | 10K | B13 / E13 | HOLD / +5N
C1 | 100n | G1 / I1 | +5N / GND
JP1 | VIN ENABLE | F42 / G42 | +12P / VIN
R3 | 1K | P24 / S24 | HEAD1 / HEAD1_F
C2 | 100n | T24 / U24 | HEAD1_F / GND
R4 | 1K | P26 / S26 | HEAD2 / HEAD2_F
C3 | 100n | T26 / U26 | HEAD2_F / GND
R5 | 1K | P28 / S28 | HEAD3 / HEAD3_F
C4 | 100n | T28 / U28 | HEAD3_F / GND
R6 | 1K | P30 / S30 | AGE / AGE_F
C5 | 100n | T30 / U30 | AGE_F / GND
R7 | 1K | P32 / S32 | MIX / MIX_F
C6 | 100n | T32 / U32 | MIX_F / GND
R8 | 1K | P34 / S34 | AUDIO_ADC / AUDIO_FILT
C7 | 22n | S35 / U35 | AUDIO_FILT / GND
D1 | BAT85 | T34 / V34 | AUDIO_FILT / +5N
D2 | BAT85 | U36 / S36 | GND / AUDIO_FILT
C8 | 100n | U37 / V37 | GND / +5N
C9 | 10u | V39 / U39 | +5N / GND
F1 | 250mA PTC | R7 / P7 | +12_BUS / +12_FUSED
D5 | 1N5817 | N7 / L7 | +12_FUSED / +12P
F2 | 100mA PTC | R3 / P3 | -12_BUS / -12_FUSED
D6 | 1N5817 | N3 / L3 | -12_FUSED / -12P
C10 | 10u | J7 / J9 | +12P / GND
C11 | 10u | J3 / J5 | -12P / GND
C12 | 100n | F6 / H6 | +12P / GND
Rev 2.0 | 23 Sep 2026 | two 24 x 44 isolated-pad boards | physical build untested | 9 / 17

# Main Board - exact coordinates, part 2

These lead holes are authoritative when labels crowd the placement drawing.

Ref | Value | Lead holes | Nets
C13 | 100n | F7 / H7 | -12P / GND
R9 | 10K | G3 / I3 | +5N / VREF_DIV
R10 | 10K | I4 / I7 | VREF_DIV / GND
C14 | 10u | K3 / K6 | VREF_DIV / GND
C15 | 100n | M3 / M5 | VREF_DIV / GND
C16 | 1u film | P10 / R10 | AUDIO_IN_TIP / AIN_BIASED
R11 | 1M | T10 / T13 | AIN_BIASED / VREF
R12 | 100K | Q10 / N10 | AIN_BIASED / AIN_SUM
R13 | 39K | L8 / N8 | AIN_SUM / AUDIO_ADC
C17 | 4.7u | L12 / N12 | DAC_RAW / AOUT_AC
R14 | 100K | P12 / P15 | AOUT_AC / GND
R15 | 10K | J14 / L14 | AOUT_FB / GND
R16 | 10K | N14 / P14 | AOUT_FB / AOUT_OP
R17 | 1K | R16 / T16 | AOUT_OP / AUDIO_OUT_TIP
R18 | 1K | K18 / M18 | LED_R_IN / LED_R_OUT
R19 | 1K | K20 / M20 | LED_G_IN / LED_G_OUT
R20 | 100K | A26 / D26 | REC_TIP / REC_BASE
R21 | 1M | F27 / F29 | REC_BASE / GND
D7 | 1N4148 | B28 / D28 | GND / REC_BASE
Q1 | 2N3904 | E26 / F26 / G26 | GND / REC_BASE / REC_CV
R22 | 10K | F24 / G24 | REC_CV / +5N
R23 | 100K | A36 / D36 | PLAY_TIP / PLAY_BASE
R24 | 1M | F37 / F39 | PLAY_BASE / GND
D8 | 1N4148 | B38 / D38 | GND / PLAY_BASE
Q2 | 2N3904 | E36 / F36 / G36 | GND / PLAY_BASE / PLAY_CV
R25 | 10K | F34 / G34 | PLAY_CV / +5N
Rev 2.0 | 23 Sep 2026 | two 24 x 44 isolated-pad boards | physical build untested | 10 / 17

# Main solder pass 1 - ground

Solder side, mirrored. W6-W43 is the continuous bare ground spine; all other ground links are insulated.

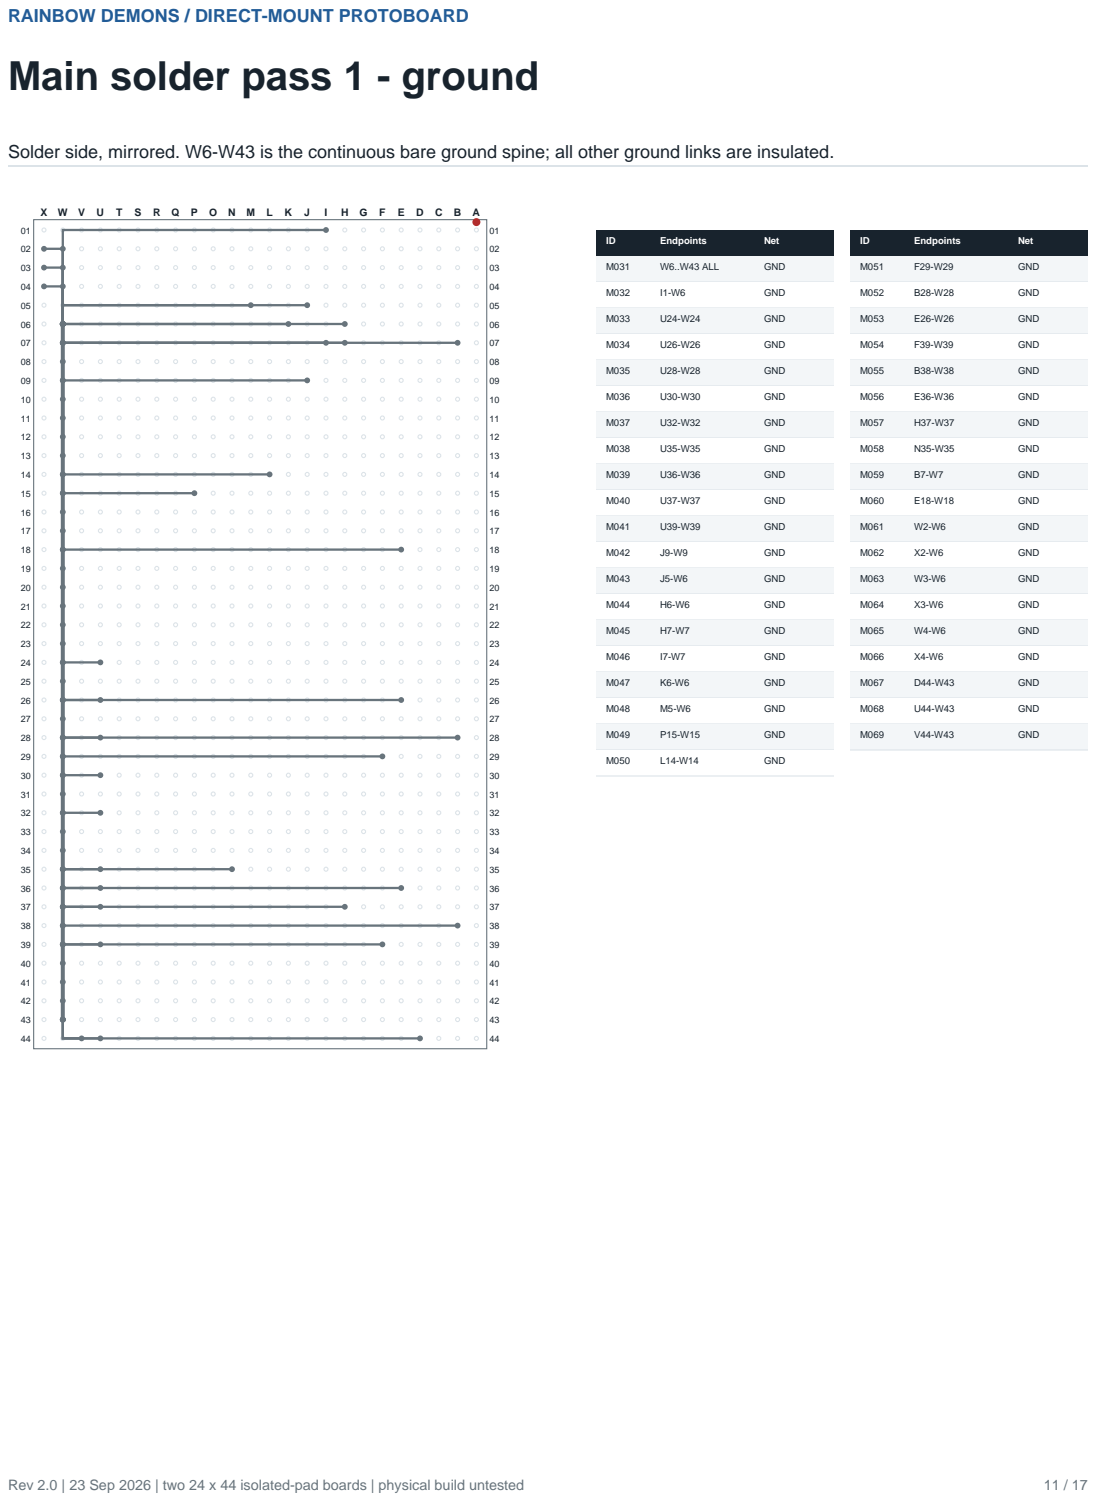
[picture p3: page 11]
Endpoints; Net; W6..W43 ALL; GND; Rev 2.0 | 23 Sep 2026 | two 24 x 44 isolated-pad boards | physical build untested

# Main wiring - power and reference

Solder side, mirrored. Check protected rails before inserting Nano, SRAM or TL074.

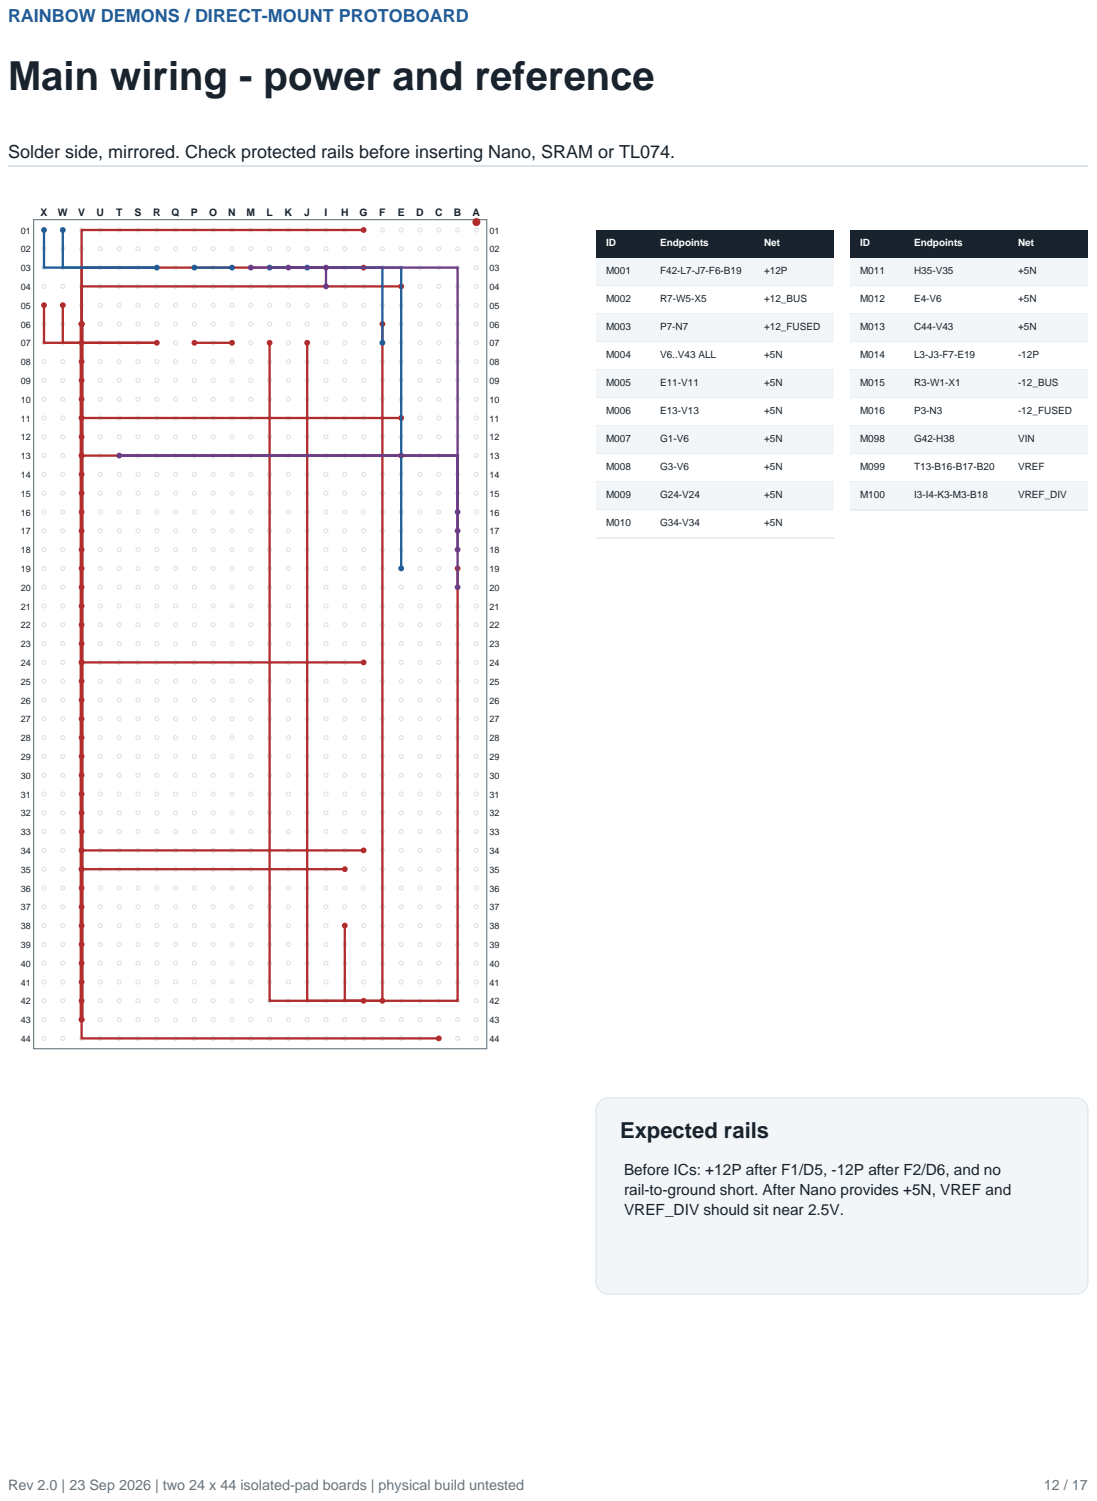
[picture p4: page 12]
Endpoints; Net; +12_BUS; +12_FUSED; V6..V43 ALL; -12_BUS; -12_FUSED; VIN; VREF; VREF_DIV; Expected rails; Rev 2.0 | 23 Sep 2026 | two 24 x 44 isolated-pad boards | physical build untested

Before ICs: +12P after F1/D5, -12P after F2/D6, and no
rail-to-ground short. After Nano provides +5N, VREF and
VREF_DIV should sit near 2.5V.

# Main solder pass 3 - SRAM and controls

Solder side, mirrored. These are the SPI, five pot, buttons, toggles and LED routes.

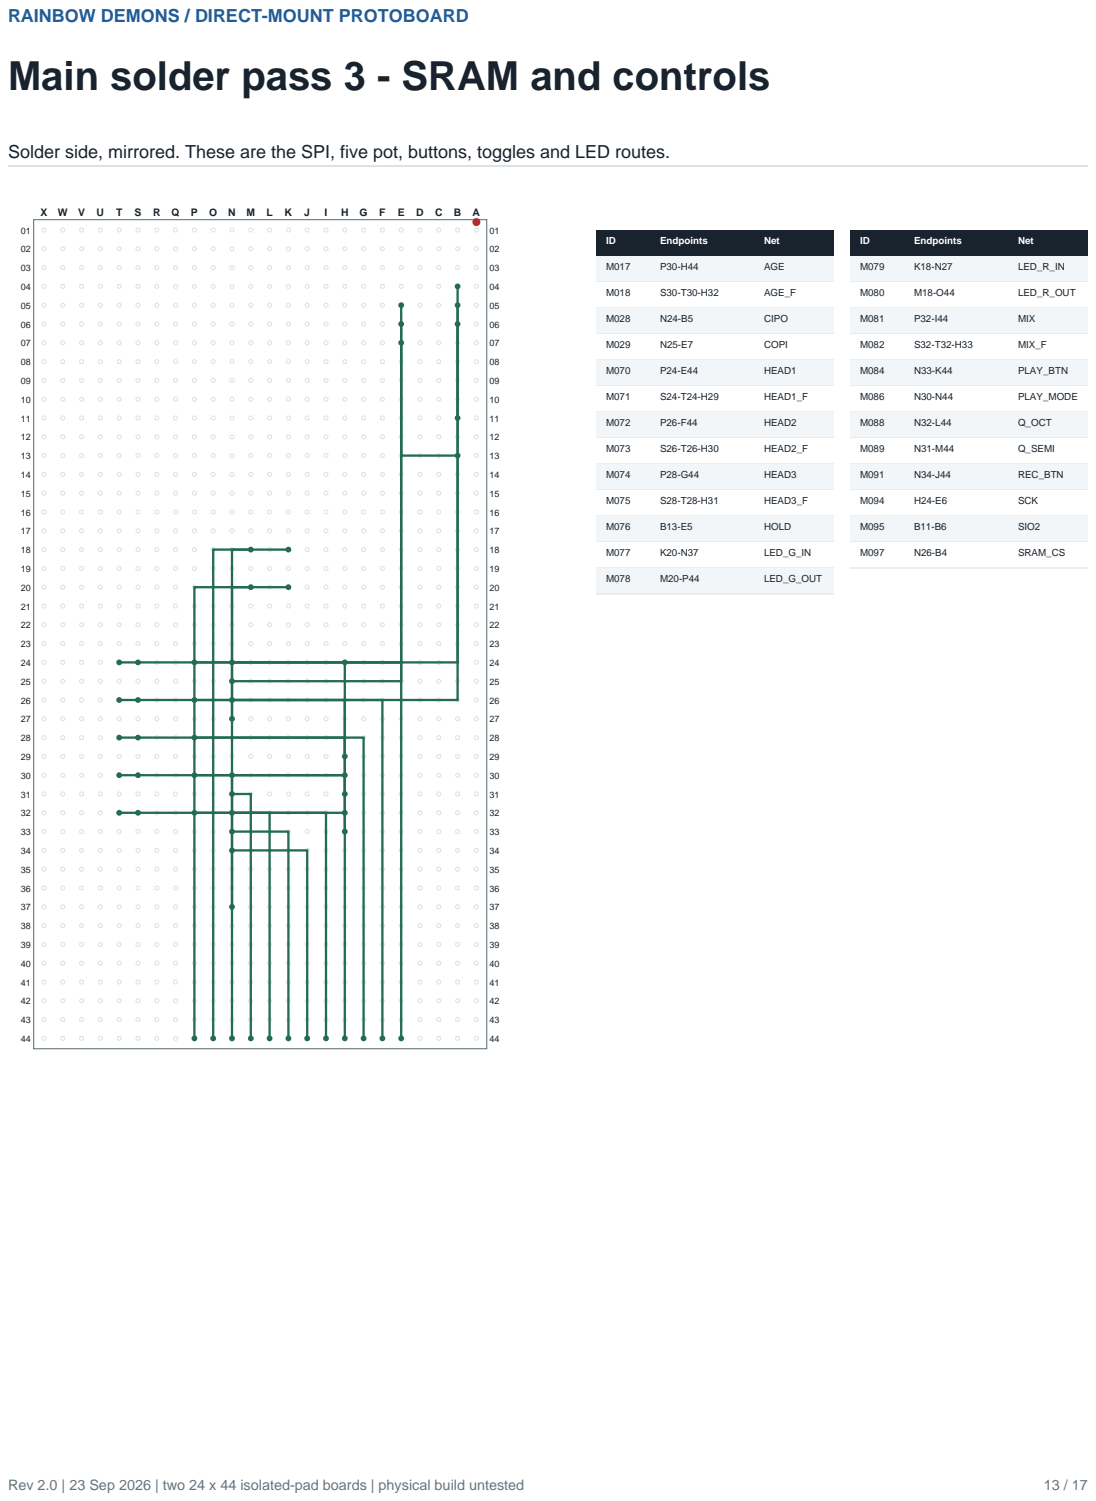
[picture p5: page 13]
Endpoints; Net; AGE; AGE_F; CIPO; COPI; HEAD1; HEAD1_F; HEAD2; HEAD2_F; HEAD3; HEAD3_F; HOLD; LED_G_IN; LED_G_OUT; LED_R_IN; LED_R_OUT; MIX; MIX_F; PLAY_BTN; PLAY_MODE; Q_OCT; Q_SEMI; REC_BTN; SCK; SIO2; SRAM_CS; Rev 2.0 | 23 Sep 2026 | two 24 x 44 isolated-pad boards | physical build untested

# Main wiring - audio path

Solder side, mirrored. Purple routes carry VREF; blue routes carry audio and DAC signals.

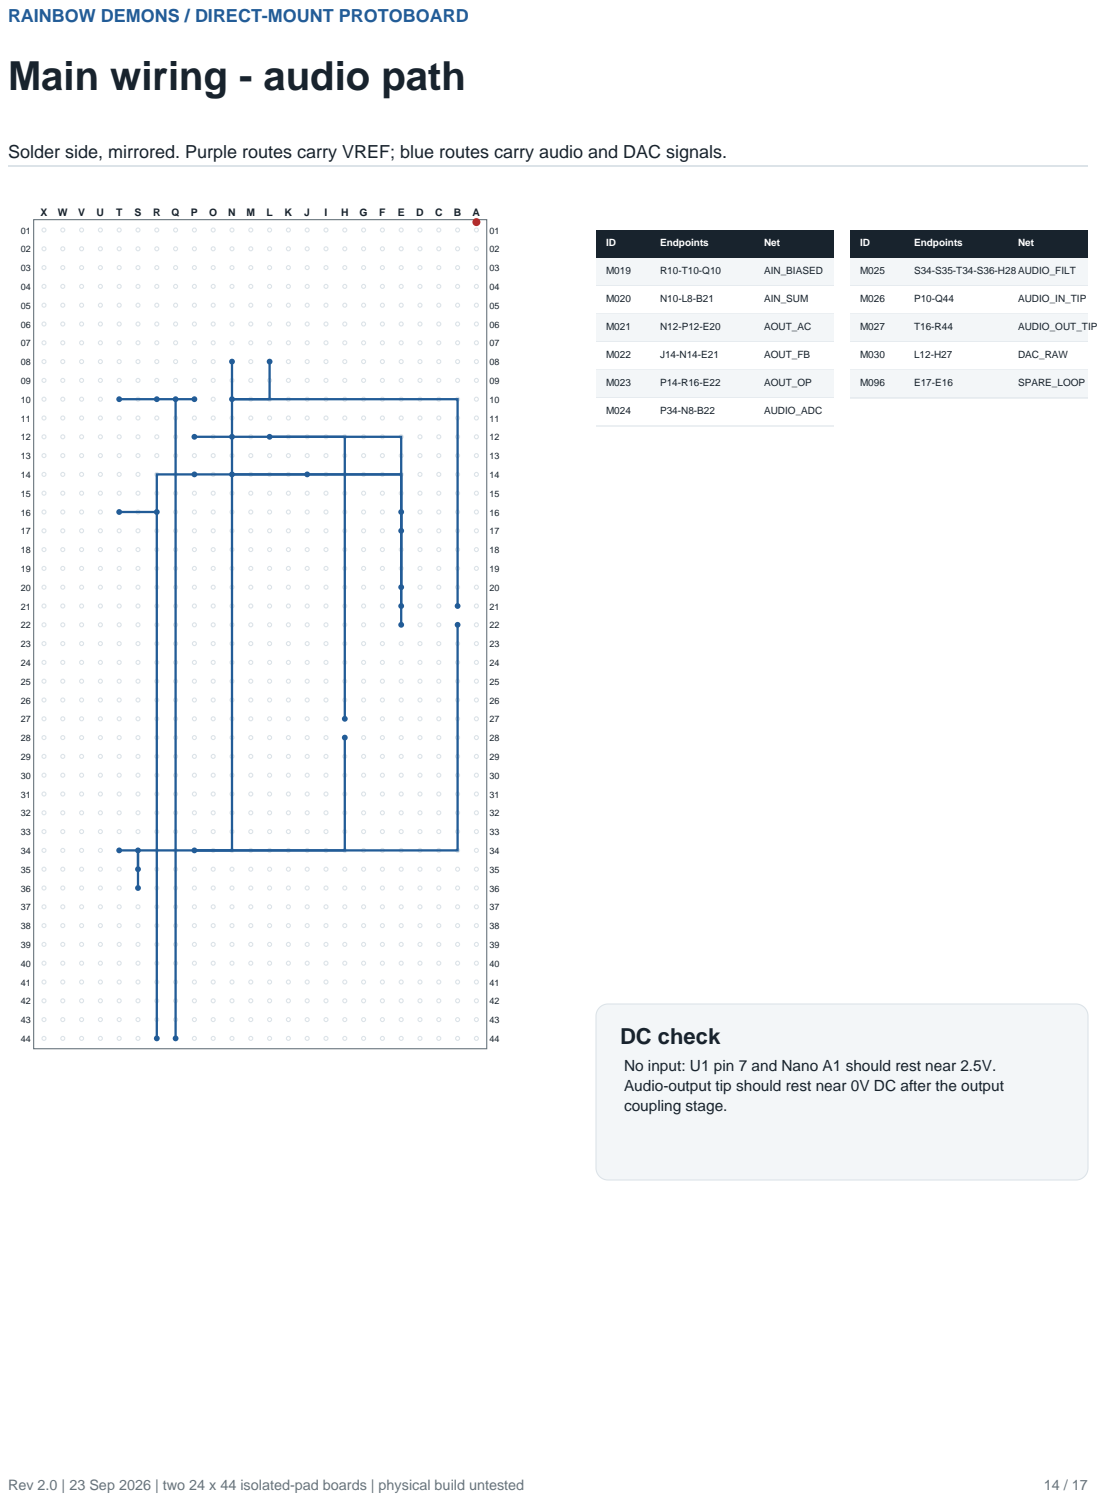
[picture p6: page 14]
Endpoints; Net; AIN_BIASED; AIN_SUM; AOUT_AC; AOUT_FB; AOUT_OP; AUDIO_ADC; S34-S35-T34-S36-H28 AUDIO_FILT; AUDIO_IN_TIP; AUDIO_OUT_TIP; DAC_RAW; SPARE_LOOP; Rev 2.0 | 23 Sep 2026 | two 24 x 44 isolated-pad boards | physical build untested

DC check
No input: U1 pin 7 and Nano A1 should rest near 2.5V.
Audio-output tip should rest near 0V DC after the output
coupling stage.

# Main solder pass 5 - Record and Play CV

Solder side, mirrored. Two identical NPN stages turn positive Eurorack pulses into protected active-low inputs.

X W V U T S R Q P O N M L K J I H G F E D C B A
01 | 01
02 | 02
03 | 03
04 | 04
05 | 05
06 | 06
07 | 07
08 | 08
09 | 09
10 | 10
11 | 11
12 | 12
13 | 13
14 | 14
15 | 15
16 | 16
17 | 17
18 | 18
19 | 19
20 | 20
21 | 21
22 | 22
23 | 23
24 | 24
25 | 25
26 | 26
27 | 27
28 | 28
29 | 29
30 | 30
31 | 31
32 | 32
33 | 33
34 | 34
35 | 35
36 | 36
37 | 37
38 | 38
39 | 39
40 | 40
41 | 41
42 | 42
43 | 43
44 | 44
ID | Endpoints | Net
M083 | D36-F37-D38-F36 | PLAY_BASE
M085 | G36-F34-N28 | PLAY_CV
M087 | A36-T44 | PLAY_TIP
ID | Endpoints | Net
M090 | D26-F27-D28-F26 | REC_BASE
M092 | G26-F24-N29 | REC_CV
M093 | A26-S44 | REC_TIP

# Transistor check

Verify the actual 2N3904 E-B-C lead order before insertion. D7/D8 anodes reach GND and bands face the base nodes.

## Collectors idle HIGH through R22/R25 and pulse LOW on a valid

positive trigger.

Rev 2.0 | 23 Sep 2026 | two 24 x 44 isolated-pad boards | physical build untested | 15 / 17

# Assembly and staged power-up

Do not insert Nano, U1 or U2 until the passive continuity and rail tests pass.

Stage | Stop point
1 | Cut two 24x44 boards. Mark A1, J1 pin 1 and all four standoff holes.
2 | Drill Top Board hardware footprints from page 4; dry-fit every exact historical part.
3 | Fit top hardware and make the short lead-to-pad bridges from page 5.
4 | Complete Top Board bus and signal passes; meter J1 pins against page 3.
5 | Fit Main Board sockets, parts and J_PWR; leave Nano/U1/U2 out.
6 | Complete Main solder passes in order and meter every rail.
7 | Power Main Board current-limited. Confirm +12P, -12P, +5N and 2.5V VREF.
8 | Fit U1, then Nano, then U2. Test each stage before stacking.
9 | Install four standoffs, align J1 C44 on both boards, then stack.
10 | Run diagnostic firmware before audio firmware.

# USB rule

For USB-only flashing, remove the module from the rack, open JP1 and separate J1. Never let USB back-power the unpowered TL074/audio board through signal clamps. Reconnect J1 only after USB is removed or the rack is intentionally powered under the documented test condition.

Rev 2.0 | 23 Sep 2026 | two 24 x 44 isolated-pad boards | physical build untested | 16 / 17

# Actual-size board grids and build record

Print at 100%. Both grids below are true 2.54mm pitch; all earlier placement drawings are enlarged.

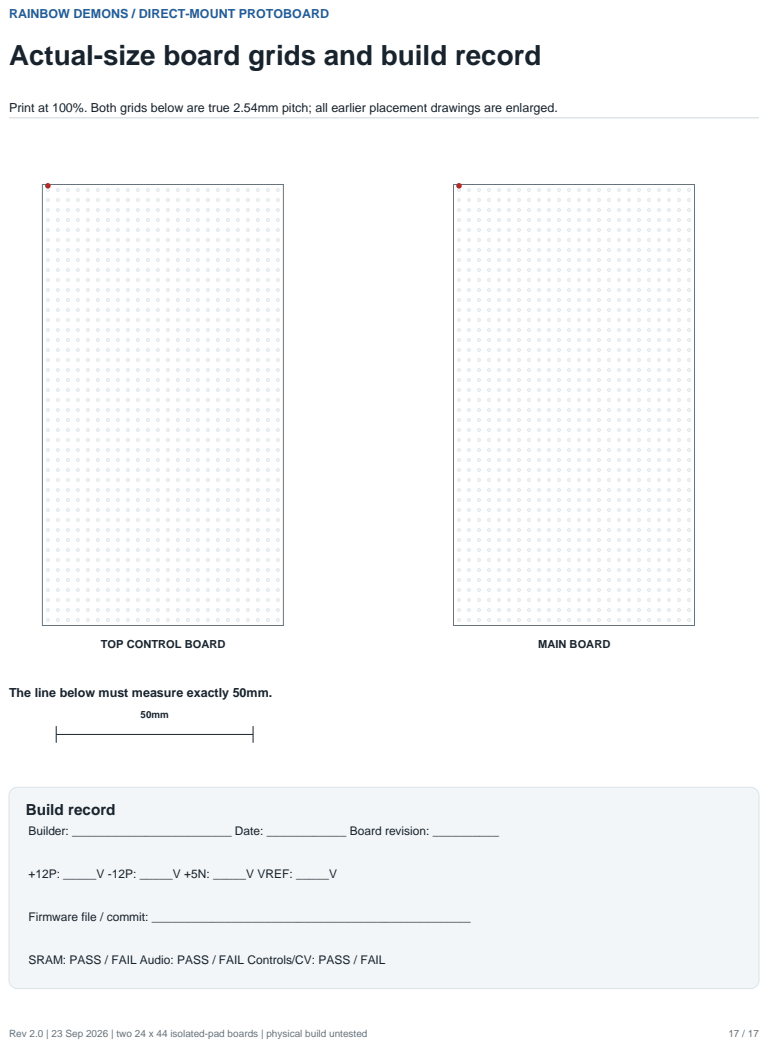
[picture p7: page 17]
TOP CONTROL BOARD; MAIN BOARD; +12P: _____V -12P: _____V +5N: _____V VREF: _____V; Rev 2.0 | 23 Sep 2026 | two 24 x 44 isolated-pad boards | physical build untested

The line below must measure exactly 50mm.

Build record
Builder: ________________________ Date: ____________ Board revision: __________

Firmware file / commit: ________________________________________________

SRAM: PASS / FAIL Audio: PASS / FAIL Controls/CV: PASS / FAIL

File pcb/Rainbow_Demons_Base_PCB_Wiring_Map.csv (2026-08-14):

control | signal | patch_sm_pin | notes
TIME pot wiper | ADC_9 | A2 | Delay time knob
TIME bottom jack | CV_1 | C5 | Bottom row, column 1
FEEDBACK pot wiper | CV_7 | C8 | Feedback amount knob
FEEDBACK bottom jack | CV_2 | C4 | Bottom row, column 2
MIX pot wiper | CV_8 | C9 | Dry/wet mix knob
MIX bottom jack | CV_3 | C3 | Bottom row, column 3
FILTER pot wiper | ADC_10 | A3 | Tone/filter knob
FILTER bottom jack | CV_4 | C2 | Bottom row, column 4
FLUTTER pot wiper | ADC_11 | D9 | Wow/flutter knob
FLUTTER bottom jack | CV_5 | C6 | Bottom row, column 5
FREEZE button | FREEZE_BTN / SPI2_CS | D1 | Momentary to ground
REVERSE button | REVERSE_BTN / SDMMC1_D3 | D2 | Momentary to ground
TEMPO LED signal | LED_TEMPO / I2C1_SDA | B8 | Series resistor holes included
FREEZE LED signal | LED_FREEZE / GATE_OUT_1 | B5 | Firmware update required
REVERSE LED signal | LED_REVERSE / I2C1_SCL | B7 | Firmware update required
CLOCK input top jack | GATE_IN_1 | B10 | Top jack row, left
CLOCK output top jack | GATE_OUT_2 | B6 | Top jack row, right
Audio input left | AUDIO_IN_LEFT | B4 | Middle jack row, column 1
Audio input right | AUDIO_IN_RIGHT | B3 | Middle jack row, column 2
Audio output left | AUDIO_OUT_LEFT | B2 | Middle jack row, column 4
Audio output right | AUDIO_OUT_RIGHT | B1 | Middle jack row, column 5
IN R normal | AUDIO_IN_LEFT | B4 | IN R switched contact is normalled from IN L
OUT L normal | AUDIO_IN_LEFT | B4 | OUT L switched contact is normalled from IN L
OUT R normal | AUDIO_IN_LEFT | B4 | OUT R switched contact is normalled from IN L

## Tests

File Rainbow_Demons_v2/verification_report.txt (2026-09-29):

Rainbow Demons v2.0.1 release verification
===========================================
PASS - 2026-09-29

Firmware
--------
Clean build: PASS
Hardware flash: PASS
Hardware functional test: PASS (Tape, Slice, Scatter, Record, Reset,
three-head playback, controls and mode changes)
Former 3 kHz callback squeal: NOT AUDIBLE with 2-sample audio blocks
Audio crackling/dropouts during mode stress test: NONE REPORTED
RainbowDemons.bin: 88,252 bytes
SHA-256: C02E43BDFAF3293CE66D482667BFC05E70C1547ACF37449F2CC3C53EE25D94E8

Release artifacts
-----------------
Build guide and circuit explanation: Included
BOM: Included
Physical PCB/layout artifact: Included (KiCad source and Gerbers)
Point-to-point modifications and external wiring map: Included
Power and connector instructions: Included
Firmware source, build files and tested binary: Included
Bring-up and acceptance test: Included
Editable source files: Included
PDF visual inspection: PASS, all 6 pages
Rainbow_Demons_Build_Documentation.pdf SHA-256:
0740A80568A626E201746A196FE2E5B46F9568E27D4DAB39365A8C74E5616EDA
Rainbow_Demons_v2.0.1.zip SHA-256:
2507F2CD30DF032124D28E9DEA50F21AE611C58FC7B5DD3F1922C0E23F46027F
Rainbow_Demons_v2.0.0.zip retained unchanged; SHA-256:
43CA8191D1796DC9D0B864D95516991126F9BD38A8527209A51AD193527344C2

Carrier PCB verification inherited from v2.0.0
----------------------------------------------

Carrier outline: 91.44 x 111.50 mm (y=8.50..120.00)
Pot footprint: 2.50 mm pin pitch; 9.60 mm mounting-tab spacing
Jack footprint: S/TN/T = 0.00/3.10/11.40 mm; 3.00 mm barrel NPTH
Square pads: pot GND, jack sleeve/GND, LED cathode/GND
Patch SM: rear-side mirror checked at A1, A4, A5, A7, and A10
Jack normalization: IN L to IN R switch retained; OUT L/R switch pads unconnected
KiCad DRC: 0 violations; 0 unconnected

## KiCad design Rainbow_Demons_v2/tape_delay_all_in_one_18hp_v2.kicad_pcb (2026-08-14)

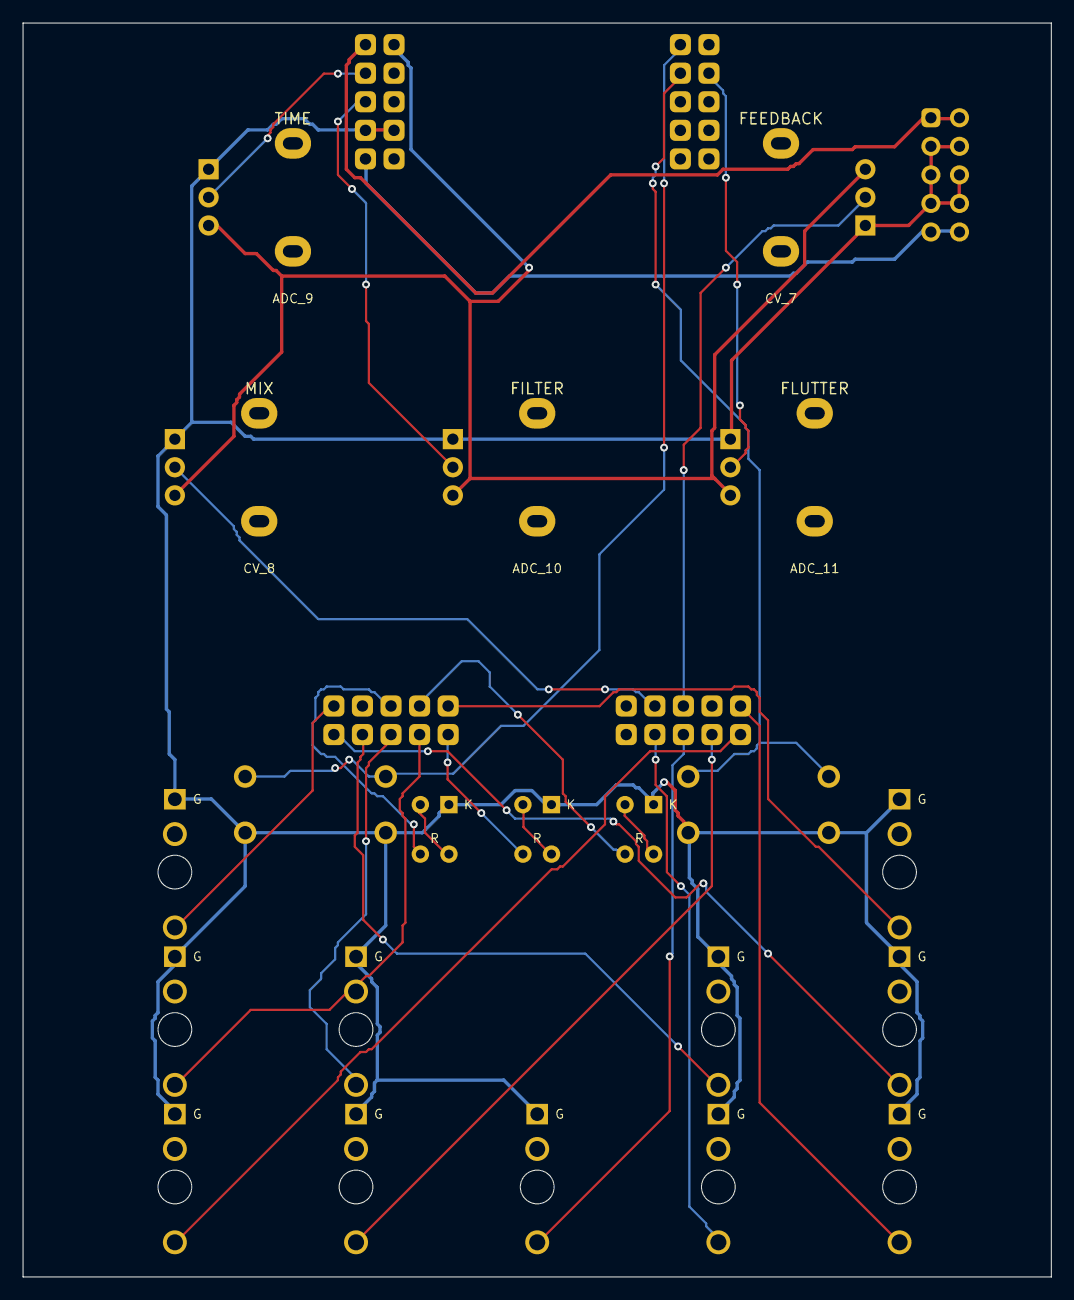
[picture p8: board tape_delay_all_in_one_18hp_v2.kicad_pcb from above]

Board: 2 copper layers, 91.4 x 111.5 mm, 34 parts (0 on the bottom side), 28 nets.

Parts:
D1: TEMPO; LED_5mm_With_Series_Resistor_Pads
D2: FREEZE; LED_5mm_With_Series_Resistor_Pads
D3: REV; LED_5mm_With_Series_Resistor_Pads
J1: CLK IN; Jack_3.5mm_QingPu_WQP-PJ398SM_ShaftOrigin
J1_BARREL, J2_BARREL, J3_BARREL, J4_BARREL, J5_BARREL, J6_BARREL, J7_BARREL, J8_BARREL, J9_BARREL, J10_BARREL, J11_BARREL: NPTH 3mm; NPTH_3mm
J2: CLK OUT; Jack_3.5mm_QingPu_WQP-PJ398SM_ShaftOrigin
J3: IN L; Jack_3.5mm_QingPu_WQP-PJ398SM_ShaftOrigin
J4: IN R; Jack_3.5mm_QingPu_WQP-PJ398SM_ShaftOrigin
J5: OUT L; Jack_3.5mm_QingPu_WQP-PJ398SM_ShaftOrigin
J6: OUT R; Jack_3.5mm_QingPu_WQP-PJ398SM_ShaftOrigin
J7: TIME; Jack_3.5mm_QingPu_WQP-PJ398SM_ShaftOrigin
J8: FEEDBACK; Jack_3.5mm_QingPu_WQP-PJ398SM_ShaftOrigin
J9: MIX; Jack_3.5mm_QingPu_WQP-PJ398SM_ShaftOrigin
J10: FILTER; Jack_3.5mm_QingPu_WQP-PJ398SM_ShaftOrigin
J11: FLUTTER; Jack_3.5mm_QingPu_WQP-PJ398SM_ShaftOrigin
J_PWR: 10 pin Eurorack power; EURORACK_10PIN_POWER_REAR
M1: Daisy Patch SM; Daisy_Patch_SM_PTH_Rear
RV1: TIME; Alpha_RD901F_9mm_Vertical_Pot_ShaftOrigin
RV2: FEEDBACK; Alpha_RD901F_9mm_Vertical_Pot_ShaftOrigin
RV3: MIX; Alpha_RD901F_9mm_Vertical_Pot_ShaftOrigin
RV4: FILTER; Alpha_RD901F_9mm_Vertical_Pot_ShaftOrigin
RV5: FLUTTER; Alpha_RD901F_9mm_Vertical_Pot_ShaftOrigin
SW1, SW2: Wurth 430476085716; Wurth_WS-TATV_430476085716_12x12_THT

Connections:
ADC_9: M1.A2, RV1.2_SIG
ADC_10: M1.A3, RV4.2_SIG
ADC_11: M1.D9, RV5.2_SIG
AUDIO_IN_LEFT: J3.TIP_SIG, J4.SW, M1.B4
AUDIO_IN_RIGHT: J4.TIP_SIG, M1.B3
AUDIO_OUT_LEFT: J5.TIP_SIG, M1.B2
AUDIO_OUT_RIGHT: J6.TIP_SIG, M1.B1
CV_1: J7.TIP_SIG, M1.C5
CV_2: J8.TIP_SIG, M1.C4
CV_3: J9.TIP_SIG, M1.C3
CV_4: J10.TIP_SIG, M1.C2
CV_5: J11.TIP_SIG, M1.C6
CV_7: M1.C8, RV2.2_SIG
CV_8: M1.C9, RV3.2_SIG
FREEZE_BTN: M1.D1, SW1.1_SIG, SW1.2_SIG
GATE_IN_1: J1.TIP_SIG, M1.B10
GATE_OUT_2: J2.TIP_SIG, M1.B6
GND: D1.K_GND, D2.K_GND, D3.K_GND, J1.SLEEVE_GND, J2.SLEEVE_GND, J3.SLEEVE_GND, J4.SLEEVE_GND, J5.SLEEVE_GND, J6.SLEEVE_GND, J7.SLEEVE_GND, J8.SLEEVE_GND, J9.SLEEVE_GND, J10.SLEEVE_GND, J11.SLEEVE_GND, J_PWR.3, J_PWR.4, J_PWR.5, J_PWR.6, J_PWR.7, J_PWR.8, M1.A4, M1.A7, RV1.1_GND, RV2.1_GND, RV3.1_GND, RV4.1_GND, RV5.1_GND, SW1.3_GND, SW1.4_GND, SW2.3_GND, SW2.4_GND
LED_FREEZE: D2.R_SIG, M1.B5
LED_FREEZE_A: D2.A, D2.R_LED_A
LED_REVERSE: D3.R_SIG, M1.B7
LED_REVERSE_A: D3.A, D3.R_LED_A
LED_TEMPO: D1.R_SIG, M1.B8
LED_TEMPO_A: D1.A, D1.R_LED_A
PWR_3V3: M1.A10, RV1.3_3V3, RV2.3_3V3, RV3.3_3V3, RV4.3_3V3, RV5.3_3V3
PWR_+12V: J_PWR.9, J_PWR.10, M1.A5
PWR_-12V: J_PWR.1, J_PWR.2, M1.A1
REVERSE_BTN: M1.D2, SW2.1_SIG, SW2.2_SIG

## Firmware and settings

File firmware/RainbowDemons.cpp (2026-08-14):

#include "daisy_patch_sm.h"

#include <cmath>
#include <cstddef>
#include <cstdint>

using namespace daisy;
using namespace daisy::patch_sm;

// Independent clean-room firmware for the Rainbow Demons Patch SM instrument.
// See the release README for the independent-design disclaimer.
namespace
{
constexpr float  kSampleRate     = 48000.0f;
constexpr size_t kMaxSamples     = static_cast<size_t>(kSampleRate * 30.0f);
constexpr size_t kMinPhrase      = 512;
constexpr float  kResetHoldMs    = 1200.0f;
constexpr float  kCrossfade      = 192.0f;

enum class Mode { Tape, Slice, Scatter };
enum class Option { Reverse, Alternate, Forward };
enum class Quantize { Octave, Free, Semitone };

struct Controls
{
    float time;       // DIR 1: playback speed and direction
    float feedback;
    float head2;      // Mode 3 DIR 2, normalized to match the other heads
    float mix;
    float q;          // pitch quantization strength/interval set
    float length;     // LEN B: delay/phrase/slice length
    Mode mode;
    Option option;
    Quantize quantize;
};

struct Head
{
    float position;
    float rate;
};

DaisyPatchSM patch;
Switch record_button;
Switch reset_button;
Switch3 mode_switch;
Switch3 option_switch;
Switch3 quantize_switch;
GPIO record_led;
GPIO status_led;

float DSY_SDRAM_BSS buffer[kMaxSamples];

// Build with RAINBOW_DEMONS_DIAGNOSTIC_NO_SDRAM_WRITE to test external-memory
// writes are coupling into the analog input. Normal builds are unchanged.
#ifndef RAINBOW_DEMONS_DIAGNOSTIC_NO_SDRAM_WRITE
#define RAINBOW_DEMONS_CAPTURE_WRITE(sample) (buffer[capture_position++] = (sample))
#else
#define RAINBOW_DEMONS_CAPTURE_WRITE(sample) (++capture_position)
#endif

Mode current_mode = Mode::Tape;
size_t write_position = 0;
size_t phrase_samples = 0;
size_t capture_position = 0;
bool phrase_ready = false;
uint32_t mode_generation = 1;
uint32_t phrase_generation = 0;
bool capturing = false;
bool capture_from_trigger = false;
bool previous_record_pressed = false;
bool reset_hold_latched = false;
float tape_position = 0.0f;
size_t tape_valid_samples = 0;
size_t previous_tape_length = 0;
bool tape_initialized = false;
float tape_filter_state = 0.0f;
float tape_wow = 0.0f;
float tape_wow_target = 0.0f;
uint32_t tape_wow_counter = 0;
float slice_position = 0.0f;
float slice_start = 0.0f;
Head scatter_heads[3] = {{0.0f, 1.0f}, {0.0f, 1.0f}, {0.0f, 1.0f}};
uint32_t random_state = 0x43543532u;
int32_t activity_samples = 0;

inline float Clamp(float x, float lo, float hi)
{
    return x < lo ? lo : (x > hi ? hi : x);
}

float CalibrateMixPot(float raw)
{
    // MIX is wired to conditioned CV_8 rather than a native unipolar ADC.
    // Allow for op-amp/rail and pot tolerance. Audio calibration of this built
    // unit measured its conditioned CW endpoint near 0.66, well below the
    // nominal rail. Use asymmetric endpoints and retain a little margin so
    // both ends land on exact digital dry/wet values.
    const float conditioned = Clamp((raw - 0.015f) * (1.0f / 0.92f), 0.0f, 1.0f);
    constexpr float dry_endpoint = 0.08f;
    constexpr float wet_endpoint = 0.62f;
    return Clamp((conditioned - dry_endpoint)
                     * (1.0f / (wet_endpoint - dry_endpoint)),
                 0.0f,
                 1.0f);
}

float CalibrateMode3Head2Pot(float raw)
{
    // Two on-panel measurements placed conditioned values 0.28 at 10:30 and
    // 0.50 at 2 o'clock. Interpolating between them puts physical noon near
    // 0.375. Map that point to the stopped-head value while retaining the
    // complete reverse/forward travel at both ends.
    const float conditioned = CalibrateMixPot(raw);
    constexpr float measured_center = 0.375f;
    if(conditioned <= measured_center)
        return 0.5f * conditioned / measured_center;
    return 0.5f
           + 0.5f * (conditioned - measured_center)
                 / (1.0f - measured_center);
}

inline float SoftClip(float x)
{
    return x / (1.0f + std::fabs(x));
}

float RandomUnit()
{
    random_state = random_state * 1664525u + 1013904223u;
    return static_cast<float>((random_state >> 8) & 0x00ffffffu)
           * (1.0f / 16777215.0f);
}

Mode ReadMode()
{
    const int p = mode_switch.Read();
    if(p == Switch3::POS_UP) return Mode::Tape;
    if(p == Switch3::POS_DOWN) return Mode::Scatter;
    return Mode::Slice;
}

Option ReadOption()
{
    const int p = option_switch.Read();
    if(p == Switch3::POS_UP) return Option::Forward;
    if(p == Switch3::POS_DOWN) return Option::Reverse;
    return Option::Alternate;
}

Quantize ReadQuantize()
{
    const int p = quantize_switch.Read();
    if(p == Switch3::POS_UP) return Quantize::Semitone;
    if(p == Switch3::POS_DOWN) return Quantize::Octave;
    return Quantize::Free;
}

Controls ReadControls()
{
    // Preserve the already-built carrier wiring exactly:
    // TIME/ADC_9, FILTER/ADC_10, FLUTTER/ADC_11,
    // FEEDBACK/CV_7 and MIX/CV_8. The five panel CV inputs remain CV_1..CV_5.
    const float time_p = Clamp(patch.GetAdcValue(ADC_9), 0.0f, 1.0f);
    const float q_p    = Clamp(patch.GetAdcValue(ADC_10), 0.0f, 1.0f);
    const float len_p  = Clamp(patch.GetAdcValue(ADC_11), 0.0f, 1.0f);
    const float fb_p   = Clamp(patch.GetAdcValue(CV_7), 0.0f, 1.0f);
    const float mix_p  = CalibrateMixPot(patch.GetAdcValue(CV_8));

    const float cv1 = Clamp(patch.GetAdcValue(CV_1), -1.0f, 1.0f);
    const float cv2 = Clamp(patch.GetAdcValue(CV_2), -1.0f, 1.0f);
    const float cv3 = Clamp(patch.GetAdcValue(CV_3), -1.0f, 1.0f);
    const float cv4 = Clamp(patch.GetAdcValue(CV_4), -1.0f, 1.0f);
    // CV_5 is the jack physically located under FLUTTER on this reused board,
    // not a normalled MIX CV. Do not let its unpatched offset prevent the Mix
    // pot from reaching either endpoint.

    Controls c;
    c.time     = Clamp(time_p + 0.25f * cv1, 0.0f, 1.0f);
    c.q        = Clamp(q_p + 0.50f * cv2, 0.0f, 1.0f);
    c.length   = Clamp(len_p + 0.50f * cv3, 0.0f, 1.0f);
    c.feedback = Clamp(fb_p + 0.50f * cv4, 0.0f, 0.985f);
    // In Mode 3 FEEDBACK becomes DIR 2.  Its own center correction puts the
    // stopped head at physical noon; increasing clockwise matches DIR 1/3.
    c.head2    = Clamp(CalibrateMode3Head2Pot(fb_p) + 0.50f * cv4,
                       0.0f,
                       1.0f);
    // Physical panel convention: CCW=dry and CW=wet. CalibrateMixPot supplies
    // hard digital endpoints despite the conditioned CV_8 pot wiring.
    c.mix      = mix_p;
    c.mode     = ReadMode();
    c.option   = ReadOption();
    c.quantize = ReadQuantize();
    return c;
}

float Wrap(float p, float length)
{
    if(length <= 1.0f) return 0.0f;
    while(p < 0.0f) p += length;
    while(p >= length) p -= length;
    return p;
}

float ReadBuffer(float p, size_t length)
{
    if(length < 2) return 0.0f;
    p = Wrap(p, static_cast<float>(length));
    const size_t i0 = static_cast<size_t>(p);
    const size_t i1 = (i0 + 1) % length;
    const float f = p - static_cast<float>(i0);
    return buffer[i0] + (buffer[i1] - buffer[i0]) * f;
}

float ReadLoopCrossfaded(float p, float start, float length, size_t storage_length)
{
    if(length < 2.0f) return 0.0f;
    p = Wrap(p, length);
    float y = ReadBuffer(start + p, storage_length);
    const float fade = Clamp(length * 0.08f, 8.0f, kCrossfade);
    if(p > length - fade)
    {
        const float x = (p - (length - fade)) / fade;
        const float beginning = ReadBuffer(start + p - length, storage_length);
        y += (beginning - y) * x;
    }
    return y;
}

float RateFromKnob(float knob, Quantize quantize, Option option)
{
    // Each DIR control spans -4x to +4x with a stationary head at noon.
    float raw_rate = (knob - 0.5f) * 8.0f;
    float direction = raw_rate < 0.0f ? -1.0f : 1.0f;
    if(option == Option::Reverse) direction = -1.0f;
    else if(option == Option::Forward) direction = 1.0f;

    const float magnitude = std::fabs(raw_rate);
    if(magnitude < 0.015f) return 0.0f;
    float semitones = 12.0f * (std::log(magnitude) / std::log(2.0f));
    if(quantize == Quantize::Semitone)
        semitones = std::floor(semitones + 0.5f);
    else if(quantize == Quantize::Octave)
        semitones = std::floor(semitones / 12.0f + 0.5f) * 12.0f;
    const float speed = quantize == Quantize::Free
                            ? magnitude : std::pow(2.0f, semitones / 12.0f);
    return direction * Clamp(speed, 0.25f, 4.0f);
}

float QuantizedRate(const Controls& c)
{
    return RateFromKnob(c.time, c.quantize, c.option);
}

float Mode3HeadRate(float knob, Quantize quantize, Option option)
{
    // Retain the established control landmarks: stop at noon and about 1x at
    // 1:30. Raising the original magnitude to 1.5 keeps unity fixed while
    // extending the endpoints to 1/8x..8x (-3 through +3 octaves).
    const float raw_rate = (knob - 0.5f) * 8.0f;
    float direction = raw_rate < 0.0f ? -1.0f : 1.0f;
    if(option == Option::Reverse) direction = -1.0f;
    else if(option == Option::Forward) direction = 1.0f;

    const float original_magnitude = std::fabs(raw_rate);
    if(original_magnitude < 0.015f) return 0.0f;
    const float magnitude = original_magnitude * std::sqrt(original_magnitude);
    float semitones = 12.0f * (std::log(magnitude) / std::log(2.0f));
    if(quantize == Quantize::Semitone)
        semitones = std::floor(semitones + 0.5f);
    else if(quantize == Quantize::Octave)
        semitones = std::floor(semitones / 12.0f + 0.5f) * 12.0f;
    const float speed = quantize == Quantize::Free
                            ? magnitude : std::pow(2.0f, semitones / 12.0f);
    return direction * Clamp(speed, 0.125f, 8.0f);
}

size_t LengthSamples(float length, float minimum_seconds, float maximum_seconds)
{
    const float seconds = minimum_seconds
                          * std::pow(maximum_seconds / minimum_seconds, length);
    return static_cast<size_t>(Clamp(seconds * kSampleRate,
                                     static_cast<float>(kMinPhrase),
                                     static_cast<float>(kMaxSamples)));
}

size_t SteppedTapeLength(float normalized)
{
    // LEN B moves through 31.25 ms * 2^n: 31, 62, 125, 250, 500 ms,
    // then 1, 2, 4 and 8 seconds. The hard jumps are part of the instrument.
    const int step = static_cast<int>(Clamp(normalized, 0.0f, 0.9999f) * 9.0f);
    return static_cast<size_t>(0.03125f * kSampleRate
                               * static_cast<float>(1u << step));
}

float LoFiQuantize(float x)
{
    // Roughly 11-bit audio after saturation: audible texture without turning
    // quiet passages into a harsh bitcrusher.
    return std::floor(Clamp(x, -1.0f, 1.0f) * 1024.0f + 0.5f) * (1.0f / 1024.0f);
}

void ResetHeads()
{
    tape_position = 0.0f;
    tape_initialized = false;
    tape_filter_state = 0.0f;
    slice_position = 0.0f;
    slice_start = 0.0f;
    scatter_heads[0] = {0.0f, 1.0f};
    scatter_heads[1] = {phrase_samples * 0.333f, 1.0f};
    scatter_heads[2] = {phrase_samples * 0.667f, 1.0f};
    activity_samples = static_cast<int32_t>(0.03f * kSampleRate);
}

void ClearMemory()
{
    phrase_samples = 0;
    capture_position = 0;
    write_position = 0;
    phrase_ready = false;
    phrase_generation = 0;
    capturing = false;
    capture_from_trigger = false;
    tape_valid_samples = 0;
    previous_tape_length = 0;
    ResetHeads();
}

void BeginCapture(bool from_trigger)
{
    capture_position = 0;
    phrase_samples = 0;
    phrase_ready = false;
    phrase_generation = 0;
    capturing = true;
    capture_from_trigger = from_trigger;
    ResetHeads();
}

void EndCapture()
{
    capturing = false;
    capture_from_trigger = false;
#ifdef RAINBOW_DEMONS_DIAGNOSTIC_NO_SDRAM_WRITE
    // The diagnostic deliberately leaves SDRAM untouched. Do not declare an
    // unwritten phrase playable when Record is released.
    phrase_samples = 0;
    phrase_ready = false;
    ResetHeads();
#else
    if(capture_position >= kMinPhrase)
    {
        phrase_samples = capture_position;
        phrase_generation = mode_generation;
        phrase_ready = true;
        ResetHeads();
    }
#endif
}

void OnModeChanged(Mode next)
{
    ++mode_generation;
    if(mode_generation == 0) mode_generation = 1;
    current_mode = next;
    // Each mode starts as a separate instrument with an empty buffer. This
    // prevents a Mode 2 phrase or Mode 3 loop leaking into the next mode.
    ClearMemory();
}

float ProcessTape(float input, const Controls& c)
{
    const size_t delay_length = SteppedTapeLength(c.length);
    float rate = QuantizedRate(c);

    if(!tape_initialized || previous_tape_length != delay_length)
    {
        write_position %= delay_length;
        tape_position = static_cast<float>((write_position + 1) % delay_length);
        previous_tape_length = delay_length;
        tape_initialized = true;
    }

    // A freely moving read head produces the characteristic pitch/reverse delay.
    float wet = tape_valid_samples >= delay_length
                    ? ReadLoopCrossfaded(tape_position, 0.0f,
                                        static_cast<float>(delay_length), delay_length)
                    : 0.0f;

    // Fixed, very slow speed wander and a one-pole bandwidth limit supply the
    // imperfect converter/tape feel without sacrificing pitch tracking.
    if(++tape_wow_counter >= 2400)
    {
        tape_wow_counter = 0;
        tape_wow_target = (RandomUnit() * 2.0f - 1.0f) * 0.012f;
    }
    tape_wow += (tape_wow_target - tape_wow) * 0.0008f;
    rate += tape_wow;

    const float cutoff = 0.015f + 0.42f * c.q * c.q;
    tape_filter_state += cutoff * (wet - tape_filter_state);
    wet = LoFiQuantize(tape_filter_state);
    buffer[write_position] = LoFiQuantize(
        SoftClip(input * 1.15f + wet * c.feedback * 1.35f));
    write_position = (write_position + 1) % delay_length;
    if(tape_valid_samples < delay_length) ++tape_valid_samples;

    tape_position = Wrap(tape_position + rate, static_cast<float>(delay_length));
    return wet;
}

float ProcessSlice(float input, const Controls& c)
{
    if(capturing)
    {
        const size_t limit = static_cast<size_t>(4.0f * kSampleRate);
        if(capture_position < limit) RAINBOW_DEMONS_CAPTURE_WRITE(LoFiQuantize(SoftClip(input)));
        if(capture_position >= limit) EndCapture();
        return input;
    }
    if(!phrase_ready || phrase_generation != mode_generation) return 0.0f;

    const size_t requested = LengthSamples(c.length, 0.010f, 4.0f);
    const float slice_length = static_cast<float>(requested < phrase_samples
                                                    ? requested : phrase_samples);
    const float rate = QuantizedRate(c);
    const float wet = ReadLoopCrossfaded(slice_position, slice_start,
                                         slice_length, phrase_samples);
    slice_position += rate;
    if(slice_position >= slice_length || slice_position < 0.0f)
    {
        slice_position = rate < 0.0f ? slice_length - 1.0f : 0.0f;
        const float available = static_cast<float>(phrase_samples) - slice_length;
        // Q also raises the probability/range of asynchronous random jumps.
        if(RandomUnit() < (0.12f + 0.85f * c.q))
            slice_start = RandomUnit() * (available > 0.0f ? available : 0.0f);
        activity_samples = static_cast<int32_t>(0.02f * kSampleRate);
    }
    return wet;
}

float ProcessScatter(float input, const Controls& c)
{
    if(capturing)
    {
        const size_t limit = static_cast<size_t>(8.0f * kSampleRate);
        if(capture_position < limit) RAINBOW_DEMONS_CAPTURE_WRITE(LoFiQuantize(SoftClip(input)));
        if(capture_position >= limit) EndCapture();
        return input;
    }
    if(!phrase_ready || phrase_generation != mode_generation) return 0.0f;

    const int heads = 1 + static_cast<int>(Clamp(c.length, 0.0f, 0.9999f) * 3.0f);
    const float loop_length = static_cast<float>(phrase_samples);
    const float rates[3] = {
        Mode3HeadRate(c.time, c.quantize, c.option),
        Mode3HeadRate(c.head2, c.quantize, c.option),
        Mode3HeadRate(c.q, c.quantize, c.option)};
    float wet = 0.0f;
    for(int h = 0; h < heads; ++h)
    {
        wet += ReadLoopCrossfaded(scatter_heads[h].position, 0.0f,
                                  loop_length, phrase_samples);
        const float rate = rates[h] * scatter_heads[h].rate;
        scatter_heads[h].position = Wrap(scatter_heads[h].position + rate, loop_length);

        // Quantized modes occasionally produce musical random steps. Free mode
        // stays fully manual and behaves like a straightforward multi-head tape loop.
        if(c.quantize != Quantize::Free
           && RandomUnit() < (0.0000015f + 0.0000015f * static_cast<float>(heads)))
        {
            const int step = static_cast<int>(RandomUnit() * 9.0f) - 4;
            scatter_heads[h].rate = std::pow(2.0f, step / 12.0f);
            scatter_heads[h].position = RandomUnit() * loop_length;
            activity_samples = static_cast<int32_t>(0.02f * kSampleRate);
        }
    }
    return wet / static_cast<float>(heads);
}

void AudioCallback(AudioHandle::InputBuffer in,
                   AudioHandle::OutputBuffer out,
                   size_t size)
{
    patch.ProcessAllControls();
    record_button.Debounce();
    reset_button.Debounce();
    const Controls c = ReadControls();

    if(c.mode != current_mode) OnModeChanged(c.mode);

    const bool record_pressed = record_button.Pressed();
    const bool record_trigger = patch.gate_in_1.Trig();
    if(c.mode != Mode::Tape)
    {
        if(record_pressed && !previous_record_pressed) BeginCapture(false);
        if(record_trigger) BeginCapture(true);
        if(!record_pressed && previous_record_pressed) EndCapture();
        // A trigger starts a bounded capture when there is no physical hold/release.
        if(record_trigger && !record_pressed) capturing = true;
    }
    previous_record_pressed = record_pressed;

    const bool reset_trigger = patch.gate_in_2.Trig();
    if(reset_button.RisingEdge() || reset_trigger) ResetHeads();
    if(reset_button.Pressed() && reset_button.TimeHeldMs() >= kResetHoldMs)
    {
        if(!reset_hold_latched)
        {
            ClearMemory();
            reset_hold_latched = true;
        }
    }
    else if(!reset_button.Pressed()) reset_hold_latched = false;

    for(size_t i = 0; i < size; ++i)
    {
        const float input = Clamp(IN_L[i], -2.0f, 2.0f);
        float wet = 0.0f;
        if(c.mode == Mode::Tape) wet = ProcessTape(input, c);
        else if(c.mode == Mode::Slice) wet = ProcessSlice(input, c);
        else wet = ProcessScatter(input, c);

        // A trigger has no release edge, so give it the native mode maximum.
        const size_t trigger_limit = c.mode == Mode::Slice
                                         ? static_cast<size_t>(4.0f * kSampleRate)
                                         : static_cast<size_t>(8.0f * kSampleRate);
        if(capturing && capture_from_trigger && capture_position >= trigger_limit)
            EndCapture();

        float y;
        if(capturing)
            y = input; // transparent live monitoring while recording a phrase
        else if(c.mix <= 0.0f)
            y = input; // true digital dry: no wet leakage and no DSP waveshaping
        else if(c.mix >= 1.0f)
            y = SoftClip(wet); // true digital wet: no direct-signal leakage
        else
            y = SoftClip(input * (1.0f - c.mix) + wet * c.mix);
        OUT_L[i] = y;
        OUT_R[i] = y;
        if(activity_samples > 0) --activity_samples;
    }

    record_led.Write(capturing);
    status_led.Write((c.mode == Mode::Tape || phrase_ready) && activity_samples <= 0);
    patch.SetLed(c.mode == Mode::Tape || phrase_ready);
}
} // namespace

int main(void)
{
    patch.Init();
    patch.SetAudioSampleRate(kSampleRate);
    patch.SetAudioBlockSize(16);

    // These pins exactly match the already-built carrier and existing guide.
    record_button.Init(DaisyPatchSM::D1);
    reset_button.Init(DaisyPatchSM::D2);
    mode_switch.Init(DaisyPatchSM::D7, DaisyPatchSM::D10);
    option_switch.Init(DaisyPatchSM::D3, DaisyPatchSM::D4);
    quantize_switch.Init(DaisyPatchSM::D5, DaisyPatchSM::D6);
    record_led.Init(DaisyPatchSM::B8, GPIO::Mode::OUTPUT);
    status_led.Init(DaisyPatchSM::B7, GPIO::Mode::OUTPUT);
    record_led.Write(false);
    status_led.Write(false);
    patch.SetLed(false);
    ClearMemory();
    patch.StartAudio(AudioCallback);
    while(true) {}
}

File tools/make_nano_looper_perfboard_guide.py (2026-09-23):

from pathlib import Path
from collections import Counter
from reportlab.pdfgen import canvas
from reportlab.lib.pagesizes import letter
from reportlab.lib.colors import HexColor, white
from reportlab.lib.styles import ParagraphStyle
from reportlab.platypus import Paragraph
from reportlab.pdfbase.pdfmetrics import stringWidth

from nano_r4_looper_perfboard_model import (
    COLS, ROWS, MOUNT_PADS, xy, validate,
    CORE_PARTS, CORE_WIRES, CORE_J1, NANO, SRAM,
    INTERFACE_PARTS, INTERFACE_WIRES, INTERFACE_J1, U1, J2, J3, JPWR,
)

ROOT = Path(__file__).resolve().parents[1]
OUT = ROOT / "output" / "pdf"
OUT.mkdir(parents=True, exist_ok=True)
PDF = OUT / "Rainbow_Demons_Nano_R4_Three_Head_Looper_Build_Guide.pdf"

validate()

W, H = letter
INK = HexColor("#18232d")
GRAY = HexColor("#68747c")
LIGHT = HexColor("#dce3e8")
PALE = HexColor("#f3f6f8")
BLUE = HexColor("#225c97")
RED = HexColor("#b12c2c")
GREEN = HexColor("#236c51")
AMBER = HexColor("#a96512")
PURPLE = HexColor("#6c3d86")

c = canvas.Canvas(str(PDF), pagesize=letter)
c.setTitle("Rainbow Demons Nano R4 Looper - Exact Perfboard Build Guide")
c.setAuthor("Rainbow Demons DIY documentation")
c.setSubject("Exact 24 x 36 isolated-pad placements and connections")
TOTAL = 19
page_no = 0


def txt(x, y, s, size=9, bold=False, color=INK, align="left"):
    c.setFillColor(color)
    c.setFont("Helvetica-Bold" if bold else "Helvetica", size)
    {"left": c.drawString, "right": c.drawRightString, "center": c.drawCentredString}[align](x, y, str(s))


def para(x, y, s, width, size=9, leading=None, color=INK):
    st = ParagraphStyle("p", fontName="Helvetica", fontSize=size,
                        leading=leading or size * 1.3, textColor=color)
    p = Paragraph(s, st)
    _, hh = p.wrap(width, 900)
    assert y - hh >= 30, (page_no, y, hh, s[:60])
    p.drawOn(c, x, y - hh)
    return y - hh


def box(x, y, w, h, title=None, fill=PALE):
    c.setFillColor(fill); c.setStrokeColor(LIGHT); c.setLineWidth(.7)
    c.roundRect(x, y, w, h, 5, fill=1, stroke=1)
    if title:
        txt(x + 12, y + h - 19, title, 11, True)


def header(title, sub):
    global page_no
    page_no += 1
    txt(36, 760, "RAINBOW DEMONS / EXACT PERFBOARD REFERENCE", 8.6, True, BLUE)
    txt(36, 731, title, 20.5, True)
    para(36, 711, sub, 540, 9.2, 12)
    c.setStrokeColor(LIGHT); c.line(36, 685, 576, 685)
    txt(36, 20, "Rev 1.1 | 23 Sep 2026 | perimeter headers | Physical build untested", 7.5, color=GRAY)
    txt(576, 20, f"{page_no} / {TOTAL}", 7.5, color=GRAY, align="right")


def end(): c.showPage()


def table(x, y, width, headers, rows, colwidths, rowh=20, size=8, wrap=False):
    assert abs(sum(colwidths) - width) < .1
    c.setFillColor(INK); c.rect(x, y-rowh, width, rowh, fill=1, stroke=0)
    xx = x
    for h, cw in zip(headers, colwidths):
        txt(xx+5, y-rowh+6, h, size, True, white); xx += cw
    y -= rowh
    for i, row in enumerate(rows):
        rh = rowh
        if wrap:
            counts = [max(1, int((stringWidth(str(v), "Helvetica", size)+cw-12)//(cw-10)))
                      for v, cw in zip(row, colwidths)]
            rh = max(rowh, max(counts) * size * 1.2 + 6)
        c.setFillColor(PALE if i % 2 == 0 else white); c.rect(x, y-rh, width, rh, fill=1, stroke=0)
        xx = x
        for val, cw in zip(row, colwidths):
            val = str(val)
            if wrap and stringWidth(val, "Helvetica", size) > cw-10:
                st = ParagraphStyle("cell", fontName="Helvetica", fontSize=size, leading=size*1.15, textColor=INK)
                p = Paragraph(val, st); _, ph = p.wrap(cw-10, rh-3); p.drawOn(c, xx+5, y-3-ph)
            else:
                assert stringWidth(val, "Helvetica", size) <= cw-8, (page_no, val, cw)
                txt(xx+5, y-rh+(rh-size)/2+1, val, size)
            xx += cw
        c.setStrokeColor(LIGHT); c.line(x, y-rh, x+width, y-rh)
        y -= rh
    assert y >= 30, ("table low", page_no, y)
    return y


def check(x, y, s, width=530, size=8.7):
    c.setStrokeColor(INK); c.rect(x, y-1, 6, 6, fill=0, stroke=1)
    return para(x+15, y+7, s, width-15, size) - 5
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

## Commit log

2026-08-14 Release Rainbow Demons v2.0.0
    [Rainbow_Demons_Base_PCB_Wiring_Map.csv]
2026-09-23 Add printable Nano R4 looper build guide
2026-09-23 Replace Nano looper guide with exact perfboard build
    [make_nano_looper_perfboard_guide.py, nano_r4_looper_perfboard_model.py]
2026-09-23 Rework Nano looper as direct-mount two-board build
    [make_nano_r4_integrated_guide.py, nano_r4_integrated_looper_model.py]
2026-09-29 Release Rainbow Demons v2.0.1 noise fix
    [make_rainbow_demons_release_pdf.py]
